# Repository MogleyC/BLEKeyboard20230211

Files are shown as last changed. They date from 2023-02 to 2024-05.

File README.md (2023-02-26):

# BLEKeyboard20230211

해당 제작물의 모든 소유권(소스,정보,파일,개발과정, 결과물 등)은 Mogley가 갖는다.
Mogley가 지정한 소속 관리자 및 개별 지정 담당자 외 일체의 열람/복사/사용을 금한다.
무단 열람/복사/사용이 되는 경우 해당 개인/단체에 법적 책임을 물을 수 있다.
이 외 상세사항 및 권한변경은 Mogley가 지정한 규정에 의거한다.

BLEKeyboard20230211는 주로 BLEKeyboard를 개발/관리를 위해 제작되었다.
BLEKeyboard의 주 개발 목표는 다음과 같다.
 - nRF MCU를 통한 프로젝트 개발
 - 프로젝트 회로도 및 PCB 설계 및 제작
 - 제품의 실제 구현 및 그에 필요한 작업 일체에 대한 개발 내용 정리

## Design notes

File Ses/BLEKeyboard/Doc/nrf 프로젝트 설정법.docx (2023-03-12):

NRF 프로젝트 설정법

# I. 신규 프로젝트 생성 및 설정

## New Solution & New Project(File->New Project)

### C/C++ executable for Nordic Semiconductor nRF

### Target Processor : nRF52832_xxAA or nRF52810_xxAA

### Compiler : gcc

### Additional Output Format : hex

### Printf Integer Support : Long

### Printf Width/Precision Supported : Yes

### Scanf Integer Support : Long)

### Select files to add to project : Files 및 Import all files and package files 체크 해제. nRF5_SDK파일들을 이용한다.

## nRF5_SDK용 config setting

### 다음의 두개의 파일을 복사

#### nRF5_SDK 폴더/config/칩셋종류/config/sdk_config.h

#### nRF5_SDK 폴더/config/칩셋종류/ses/flash_placement.xml

#### 단, 참고하고자 하는 SDK 샘플이 있는 경우 해당 프로젝트에 있는 파일을 복사

### 다음의 위치에 붙여넣기

#### SRC/칩셋종류/

### sdk_config.h의 사용하는 칩셋/모듈에 따라 셋팅 값을 조정해 주어야 한다.

## 프로젝트 설정(프로젝트 우클릭->Optoin->BuildType : Common)

### Build

#### Project Directory : nRF52832 (Optional)

#### Project Macoros

nRFSdkVer=nrf52832

nRFSoftDeviceVer=s132

nRFSdkPath=../../nRF5_SDK

SrcPath=../SRC

CMSIS_CONFIG_TOOL=../../nRF5_SDK/external_tools/cmsisconfig/CMSIS_Configuration_Wizard.jar

(빌드에 따라 nRFSdkVer와 nRFSoftDeviceVer를 수정할 것)

#### Property Groups File : None

### Code Generation

#### Debugging Level : Level3 (Optional for DebugBuild)

### Library

#### Library I/O : None

### Linker

#### Linker : GNU

#### Memory Map File : None

#### Memory Segments : FLASH1 RX 0x0 0x80000;RAM1 RWX 0x20000000 0x10000 (참고하고자 하는 SDK 샘플에서 확인)

#### Section Placement File : $(SrcPath)/$(nRFSdkVer)/$(nRFSoftDeviceVer)/flash_placement.xml

#### Section Placement Macros : 참고하고자 하는 SDK 샘플에서 확인

### Preprocessor

#### Preprocessor Definitions

NRF52832_XXAA

NRF52

NRF52_PAN_74

FLOAT_ABI_HARD

CONFIG_GPIO_AS_PINRESET

INITIALIZE_USER_SECTIONS

S132

SOFTDEVICE_PRESENT

NO_VTOR_CONFIG

NRF_SD_BLE_API_VERSION=7

APP_TIMER_V2

APP_TIMER_V2_RTC1_ENABLED

(빌드에 따라 NRF528xx_XXAA와 S1xx를 수정할 것)

(참고하고자 하는 SDK 샘플에서 확인. 특히 소프트디바이스 버전 부분-S132)

#### User Incldue Directories

$(SrcPath)

$(SrcPath)/$(nRFSdkVer)/$(nRFSoftDeviceVer)

$(nRFSdkPath)/modules/nrfx/mdk

$(nRFSdkPath)/components

$(nRFSdkPath)/components/libraries/util

$(nRFSdkPath)/components/toolchain/cmsis/include

$(nRFSdkPath)/components/softdevice/common

$(nRFSdkPath)/components/softdevice/s132/headers

$(nRFSdkPath)/components/softdevice/s132/headers/nrf52

(이 외 참조할 폴더를 모두 넣기)

(절대참조가 아닌 상대참조$(nRFSdkPath)로 수정할것)

(참고하고자 하는 SDK 샘플에서 확인. 특히 소프트디바이스 버전 부분-S132)

### Printf/Scanf

#### Printf Integer Support : Long

#### Printf Width/Precision Supported : Yes

#### Scanf Integer Support : Long)

### Runtime Memory Area

#### Heap Size : 8192 (Optional) (참고하고자 하는 SDK 샘플에서 확인)

#### Main Stack Size : 8192 (Optional) (참고하고자 하는 SDK 샘플에서 확인)

#### Process Stack Size : 0 (Optional) (참고하고자 하는 SDK 샘플에서 확인)

### Debugger

#### Register Definition File : $(nRFSdkPath)/modules/nrfx/mdk/nrf52.svd

#### Starting Stack Pointer Value : none (Optional)

### Loader

#### Additional Load File[0] : $(nRFSdkPath)/components/softdevice/s132/hex/s132_nrf52_7.2.0_softdevice.hex

##### 빌드에 따라 소프트디바이스 버전을 변경할 것

### Simulator

#### Memory Simulation Parameter : RWX 00000000,00100000,FFFFFFFF;RWX 20000000,00010000,CDCDCDCD

### Target Script

### Reset Script : TargetInterface.resetAndStop()

## 프로젝트 폴더 설정 및 기본 파일 복사

### 프로젝트 우클릭 -> Open Solution in Editor에 아래 내용을 프로젝트 안쪽에 삽입

<folder Name="Application">

<folder Name="SRC" />

<file file_name="$(SrcPath)/main.c" />

</folder>

<folder Name="System Files">

<folder Name="Segger Startup Files">

<file file_name="C:/Program Files/SEGGER/SEGGER Embedded Studio for ARM 7.10/source/thumb_crt0.s" />

</folder>

<folder Name="nRF_Segger_RTT">

<file file_name="$(nRFSdkPath)/external/segger_rtt/SEGGER_RTT.c" />

<file file_name="$(nRFSdkPath)/external/segger_rtt/SEGGER_RTT_Syscalls_SES.c">

<configuration Name="Common" build_exclude_from_build="Yes" />

</file>

<file file_name="$(nRFSdkPath)/external/segger_rtt/SEGGER_RTT_printf.c" />

</folder>

<file file_name="$(nRFSdkPath)/modules/nrfx/mdk/ses_startup_nrf52.s" />

<file file_name="$(nRFSdkPath)/modules/nrfx/mdk/ses_startup_nrf_common.s" />

<file file_name="$(nRFSdkPath)/modules/nrfx/mdk/system_nrf52.c" />

</folder>

<folder Name="nRF_ SDK">

<file file_name="$(SrcPath)/$(nRFSdkVer)/$(nRFSoftDeviceVer)/sdk_config.h" />

</folder>

(이 외 참조할 폴더&파일을 모두 넣기)

(절대참조가 아닌 상대참조로 수정할것)

(참고하고자 하는 SDK 샘플에서 확인)

### 구성요소

#### Application : main.c

##### SRC : 직접 제작된 소스파일들

#### System Files : ses_startup_nrf_common.s ses_startup_nrf52.s system_nrf52.c

##### nRF_Segger_RTT : SEGGER_RTT.c SEGGER_RTT_printf.c SEGGER_RTT_Syscalls_SES.c

##### Segger Startup Files: thumb_crt0.s

#### nRF_ SDK : sdk_config.h

##### nRF SDK 폴더 & 소스파일들

## SEGGER_RTT_Syscalls_SES.c 오류 수정

### https://jeonhj.tistory.com/65 참고

### “SEGGER_RTT_Syscalls_SES.c” 우클릭 -> Exclude From Build 선택

### Flash_placement.xml에서 다음을 삭제

#### name=".text" 옆의 size="0x4"를 삭제

#### name=".rodata" 옆의 size="0x4"를 삭제

## 빌드 테스트

### Main.C

#include <stdint.h>

#include <stdio.h>

int main()

{

while (1) {}

}

### 빌드하였을 경우 성공해야 정상 설정 완료

### 이후 코드 작성 시작

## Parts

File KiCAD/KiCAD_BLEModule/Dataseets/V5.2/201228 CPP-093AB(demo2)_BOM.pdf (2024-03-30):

Description | Comment | TYPE | MAKER | Quantity | Designator
CHIP CERAMIC CAP | 101K/250V | 2012 | WALSIN, SAMSUNG | 14 | C17, C19, C24, C25, C26, C27, C28, C29, C31, C32, C36, C37, C39, C40
CHIP CERAMIC CAP | 103K/25V | 1608 | WALSIN, SAMSUNG | 0 | C11, C12
CHIP CERAMIC CAP | 103K/25V | 1608 | WALSIN, SAMSUNG | 5 | C23, C38, C45, C50, C51
CHIP CERAMIC CAP | 104Z/25V | 1608 | WALSIN, SAMSUNG | 8 | C1, C2, C3, C4, C5, C7, C13, C14
CHIP CERAMIC CAP | 105Z/6.3V | 1608 | WALSIN, SAMSUNG | 1 | C8
CHIP CERAMIC CAP | 105Z/6.3V | 1608 | WALSIN, SAMSUNG | 0 | C9, C10
CHIP CERAMIC CAP | FS43X105K251EGG | 4532 | WALSIN | 8 | C21, C22, C34, C35, C43, C44, C48, C49
CHIP CERAMIC CAP | TCC1206X7R103K251DT | 3216 | CCTC | 4 | C20, C33, C42, C47
CHIP LED RED | WR106SR-W | 1608 | BRIGHT LED | 7 | D1, D2, D3, D4, D5, D6, D7
CHIP LED RGB | BL-HBHG8JE36K-TRB-T05 | 1615 | BRIGHT LED | 5 | RGB1, RGB2, RGB3, RGB4, RGB5
CHIP RESISTOR | 0RJ | 6432 | WALSIN, SAMSUNG | 1 | R138
CHIP RESISTOR | 1KF | 1608 | WALSIN, SAMSUNG | 29 | .
CHIP RESISTOR | 1KF | 1608 | WALSIN, SAMSUNG | 0 | R23, R24
CHIP RESISTOR | 2.7KF | 1608 | WALSIN, SAMSUNG | 12 | R34, R35, R36, R37, R56, R57, R58, R62, R63, R64, R65, R68
CHIP RESISTOR | 4.7KF | 1608 | WALSIN, SAMSUNG | 2 | R26, R27
CHIP RESISTOR | 8.2KF | 1608 | WALSIN, SAMSUNG | 4 | R45, R71, R95, R125
CHIP RESISTOR | 10KJ | 1608 | WALSIN, SAMSUNG | 1 | R1
CHIP RESISTOR | 10KJ | 1608 | WALSIN, SAMSUNG | 0 | R20, R21, R22
CHIP RESISTOR | 22KJ | 1608 | WALSIN, SAMSUNG | 0 | R25
CHIP RESISTOR | 47RJ | 1608 | WALSIN, SAMSUNG | 5 | R15, R16, R17, R18, R19
CHIP RESISTOR | 100KJ | 1608 | WALSIN, SAMSUNG | 52 | R32, R33, R39, R40, R44, R46, R48, R49, R51, R54, R55, R60, R61, R70, R72, R74, R75, R77, R80, R81, R82, R83, R85, R86, R87, R88, R94, R96, R98, R99, R101, R102, R104, R105, R107, R110, R111, R112, R113, R115, R116, R117, R118, R124, R126, R128, R129, R131, R132, R134, R135, R137
CHIP RESISTOR | 100RJ | 1608 | WALSIN, SAMSUNG | 4 | R43, R69, R93, R123
CHIP RESISTOR | 120RJ | 3216 | WALSIN, SAMSUNG | 4 | R31, R53, R79, R109
CHIP RESISTOR | 150KF | 2012 | WALSIN, SAMSUNG | 8 | R30, R38, R52, R59, R78, R84, R108, R114
CHIP RESISTOR | 270RF | 1608 | WALSIN, SAMSUNG | 1 | R28
CHIP RESISTOR | 390RJ | 1608 | WALSIN, SAMSUNG | 6 | R2, R3, R4, R5, R6, R7
CHIP RESISTOR | 510RF | 1608 | WALSIN, SAMSUNG | 1 | R29
CHIP TRANSISTOR | 2N5401S | SOT-23 | FIRST SILICON | 12 | Q7, Q8, Q13, Q14, Q19, Q20, Q21, Q22, Q31, Q32, Q33, Q34
CHIP TRANSISTOR | 2N5551S | SOT-23 | FIRST SILICON | 24 | Q9, Q10, Q11, Q12, Q15, Q16, Q17, Q18, Q23, Q24, Q25, Q26, Q27, Q28, Q29, Q30, Q35, Q36, Q37, Q38, Q39, Q40, Q41, Q42
CHIP TRANSISTOR | 2SA1981SY | SOT-23 | AUK | 6 | Q1, Q2, Q3, Q4, Q5, Q6
PIN HEADER | SMW2.5MM-7P | DIP-8 | YEONHO ELECTRONICS | 0 | CN1
SMD AMPLIFIER 1W | AP4890 | SOP8 | APLUS | 0 | U4
SMD BUFFER | ULN2003D1013TR | SOP-16 | STMicroelectronics | 1 | U5
SMD DIODE SCHOTTKY | MBRAF3200T3G | SMA | MDD, ON SEMICONDUCTOR | 4 | D8, D9, D10, D11
SMD DIODE TVS | SMBJ15A | SMB | SAMYANG ELECTRONICS | 1 | TVS1
SMD ELECT CAPACITOR | 220uF/6.3V | SC 6.3X5.8 | SAMYOUNG | 7 | C6, C15, C16, C18, C30, C41, C46
SMD INDUCTOR | SC7850D-221K | 7850 | SUHKWANG | 4 | L1, L2, L3, L4
SMD JACK USB C TYPE | USB-TYPE-C-31-M-17 | SMD-6 | Korean-Hroparts-Elec | 1 | CN4
SMD MCU | STM32G070RBT6 | LQFP64 | STMicroelectronics | 1 | U1
SMD MOSFET N-CHANNEL | FDT86246L | SOT223 | FAIRCHILD | 4 | FET1, FET2, FET3, FET4
SMD REGULATOR | LMT117-ADJ | SOT-223 | TGS | 1 | U6
SMD SERIAL FLASH | W25Q32JVSSIQ | SOIC-8(208mil) | WINBOND | 0 | U2
SMD VOICE | VLN1MM04S8X | SOP-8 | SYNOOS | 1 | U3
SMD WAFER | 12505WR-02 | SMD-2 | YEONHO ELECTRONICS | 1 | CN2
SMD WAFER | 12505WR-02 | SMD-2 | YEONHO ELECTRONICS | 0 | CN3
SMD WAFER | 12505WS-08(STRAIGHT) | SMD-8 | YEONHO ELECTRONICS | 1 | CN6
SMD WAFER | 12505WS-09(STRAIGHT) | SMD-9 | YEONHO ELECTRONICS | 1 | CN5
SPEAKER | TDM15A-8-L055C0.5S-0.3D | ASS'Y | NCEI | 1 | SPK1

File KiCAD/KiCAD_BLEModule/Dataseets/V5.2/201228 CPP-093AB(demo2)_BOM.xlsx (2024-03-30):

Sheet: Bill of Materials-CPP-093AB_2
Description | Comment | TYPE | MAKER | Quantity | Designator | Quantity검토수식
CHIP CERAMIC CAP | 101K/250V | 2012 | WALSIN, SAMSUNG | 14 | C17, C19, C24, C25, C26, C27, C28, C29, C31, C32, C36, C37, C39, C40 | 14 | OK
CHIP CERAMIC CAP | 103K/25V | 1608 | WALSIN, SAMSUNG | 0 | C11, C12 | 2 | Zero
CHIP CERAMIC CAP | 103K/25V | 1608 | WALSIN, SAMSUNG | 5 | C23, C38, C45, C50, C51 | 5 | OK
CHIP CERAMIC CAP | 104Z/25V | 1608 | WALSIN, SAMSUNG | 8 | C1, C2, C3, C4, C5, C7, C13, C14 | 8 | OK
CHIP CERAMIC CAP | 105Z/6.3V | 1608 | WALSIN, SAMSUNG | 1 | C8 | 1 | OK
CHIP CERAMIC CAP | 105Z/6.3V | 1608 | WALSIN, SAMSUNG | 0 | C9, C10 | 2 | Zero
CHIP CERAMIC CAP | FS43X105K251EGG | 4532 | WALSIN | 8 | C21, C22, C34, C35, C43, C44, C48, C49 | 8 | OK
CHIP CERAMIC CAP | TCC1206X7R103K251DT | 3216 | CCTC | 4 | C20, C33, C42, C47 | 4 | OK
CHIP LED RED | WR106SR-W | 1608 | BRIGHT LED | 7 | D1, D2, D3, D4, D5, D6, D7 | 7 | OK
CHIP LED RGB | BL-HBHG8JE36K-TRB-T05 | 1615 | BRIGHT LED | 5 | RGB1, RGB2, RGB3, RGB4, RGB5 | 5 | OK
CHIP RESISTOR | 0RJ | 6432 | WALSIN, SAMSUNG | 1 | R138 | 1 | OK
CHIP RESISTOR | 1KF | 1608 | WALSIN, SAMSUNG | 29 | R11, R12, R13, R14, R41, R42, R47, R50, R66, R67, R73, R76, R89, R90, R91, R92, R97, R100, R103, R106, R119, R120, R121, R122, R127, R130, R133, R136, R139 | 29 | OK
CHIP RESISTOR | 1KF | 1608 | WALSIN, SAMSUNG | 0 | R23, R24 | 2 | Zero
CHIP RESISTOR | 2.7KF | 1608 | WALSIN, SAMSUNG | 12 | R34, R35, R36, R37, R56, R57, R58, R62, R63, R64, R65, R68 | 12 | OK
CHIP RESISTOR | 4.7KF | 1608 | WALSIN, SAMSUNG | 2 | R26, R27 | 2 | OK
CHIP RESISTOR | 8.2KF | 1608 | WALSIN, SAMSUNG | 4 | R45, R71, R95, R125 | 4 | OK
CHIP RESISTOR | 10KJ | 1608 | WALSIN, SAMSUNG | 1 | R1 | 1 | OK
CHIP RESISTOR | 10KJ | 1608 | WALSIN, SAMSUNG | 0 | R20, R21, R22 | 3 | Zero
CHIP RESISTOR | 22KJ | 1608 | WALSIN, SAMSUNG | 0 | R25 | 1 | Zero
CHIP RESISTOR | 47RJ | 1608 | WALSIN, SAMSUNG | 5 | R15, R16, R17, R18, R19 | 5 | OK
CHIP RESISTOR | 100KJ | 1608 | WALSIN, SAMSUNG | 52 | R32, R33, R39, R40, R44, R46, R48, R49, R51, R54, R55, R60, R61, R70, R72, R74, R75, R77, R80, R81, R82, R83, R85, R86, R87, R88, R94, R96, R98, R99, R101, R102, R104, R105, R107, R110, R111, R112, R113, R115, R116, R117, R118, R124, R126, R128, R129, R131, R132, R134, R135, R137 | 52 | OK
CHIP RESISTOR | 100RJ | 1608 | WALSIN, SAMSUNG | 4 | R43, R69, R93, R123 | 4 | OK
CHIP RESISTOR | 120RJ | 3216 | WALSIN, SAMSUNG | 4 | R31, R53, R79, R109 | 4 | OK
CHIP RESISTOR | 150KF | 2012 | WALSIN, SAMSUNG | 8 | R30, R38, R52, R59, R78, R84, R108, R114 | 8 | OK
CHIP RESISTOR | 270RF | 1608 | WALSIN, SAMSUNG | 1 | R28 | 1 | OK
CHIP RESISTOR | 390RJ | 1608 | WALSIN, SAMSUNG | 6 | R2, R3, R4, R5, R6, R7 | 6 | OK
CHIP RESISTOR | 510RF | 1608 | WALSIN, SAMSUNG | 1 | R29 | 1 | OK
CHIP TRANSISTOR | 2N5401S | SOT-23 | FIRST SILICON | 12 | Q7, Q8, Q13, Q14, Q19, Q20, Q21, Q22, Q31, Q32, Q33, Q34 | 12 | OK
CHIP TRANSISTOR | 2N5551S | SOT-23 | FIRST SILICON | 24 | Q9, Q10, Q11, Q12, Q15, Q16, Q17, Q18, Q23, Q24, Q25, Q26, Q27, Q28, Q29, Q30, Q35, Q36, Q37, Q38, Q39, Q40, Q41, Q42 | 24 | OK
CHIP TRANSISTOR | 2SA1981SY | SOT-23 | AUK | 6 | Q1, Q2, Q3, Q4, Q5, Q6 | 6 | OK
PIN HEADER | SMW2.5MM-7P | DIP-8 | YEONHO ELECTRONICS | 0 | CN1 | 1 | Zero
SMD AMPLIFIER 1W | AP4890 | SOP8 | APLUS | 0 | U4 | 1 | Zero
SMD BUFFER | ULN2003D1013TR | SOP-16 | STMicroelectronics | 1 | U5 | 1 | OK
SMD DIODE SCHOTTKY | MBRAF3200T3G | SMA | MDD, ON SEMICONDUCTOR | 4 | D8, D9, D10, D11 | 4 | OK
SMD DIODE TVS | SMBJ15A | SMB | SAMYANG ELECTRONICS | 1 | TVS1 | 1 | OK
SMD ELECT CAPACITOR | 220uF/6.3V | SC 6.3X5.8 | SAMYOUNG | 7 | C6, C15, C16, C18, C30, C41, C46 | 7 | OK
SMD INDUCTOR | SC7850D-221K | 7850 | SUHKWANG | 4 | L1, L2, L3, L4 | 4 | OK
SMD JACK USB C TYPE | USB-TYPE-C-31-M-17 | SMD-6 | Korean-Hroparts-Elec | 1 | CN4 | 1 | OK
SMD MCU | STM32G070RBT6 | LQFP64 | STMicroelectronics | 1 | U1 | 1 | OK
SMD MOSFET N-CHANNEL | FDT86246L | SOT223 | FAIRCHILD | 4 | FET1, FET2, FET3, FET4 | 4 | OK
SMD REGULATOR | LMT117-ADJ | SOT-223 | TGS | 1 | U6 | 1 | OK
SMD SERIAL FLASH | W25Q32JVSSIQ | SOIC-8(208mil) | WINBOND | 0 | U2 | 1 | Zero
SMD VOICE | VLN1MM04S8X | SOP-8 | SYNOOS | 1 | U3 | 1 | OK
SMD WAFER | 12505WR-02 | SMD-2 | YEONHO ELECTRONICS | 1 | CN2 | 1 | OK
SMD WAFER | 12505WR-02 | SMD-2 | YEONHO ELECTRONICS | 0 | CN3 | 1 | Zero
SMD WAFER | 12505WS-08(STRAIGHT) | SMD-8 | YEONHO ELECTRONICS | 1 | CN6 | 1 | OK
SMD WAFER | 12505WS-09(STRAIGHT) | SMD-9 | YEONHO ELECTRONICS | 1 | CN5 | 1 | OK
SPEAKER | TDM15A-8-L055C0.5S-0.3D | ASS'Y | NCEI | 1 | SPK1 | 1 | OK
 |  |  |  |  |  | 14 | ZeroSum

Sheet: Bill of Materials-CPP-093AB
Description | Comment | TYPE | MAKER | Quantity | Designator
CHIP CERAMIC CAP | 101K/250V | 2012 | WALSIN, SAMSUNG | 14 | C17, C19, C24, C25, C26, C27, C28, C29, C31, C32, C36, C37, C39, C40
CHIP CERAMIC CAP | 103K/25V | 1608 | WALSIN, SAMSUNG | 7 | C11, C12, C23, C38, C45, C50, C51
CHIP CERAMIC CAP | 104Z/25V | 1608 | WALSIN, SAMSUNG | 8 | C1, C2, C3, C4, C5, C7, C13, C14
CHIP CERAMIC CAP | 105Z/6.3V | 1608 | WALSIN, SAMSUNG | 3 | C8, C9, C10
CHIP CERAMIC CAP | FS43X105K251EGG | 4532 | WALSIN | 8 | C21, C22, C34, C35, C43, C44, C48, C49
CHIP CERAMIC CAP | TCC1206X7R103K251DT | 3216 | CCTC | 4 | C20, C33, C42, C47
CHIP LED RED | WR106SR-W | 1608 | BRIGHT LED | 7 | D1, D2, D3, D4, D5, D6, D7
CHIP LED RGB | BL-HBHG8JE36K-TRB-T05 | 1615 | BRIGHT LED | 5 | RGB1, RGB2, RGB3, RGB4, RGB5
CHIP RESISTOR | 0RJ | 6432 | WALSIN, SAMSUNG | 1 | R138
CHIP RESISTOR | 1KF | 1608 | WALSIN, SAMSUNG | 31 | R11, R12, R13, R14, R23, R24, R41, R42, R47, R50, R66, R67, R73, R76, R89, R90, R91, R92, R97, R100, R103, R106, R119, R120, R121, R122, R127, R130, R133, R136, R139
CHIP RESISTOR | 2.7KF | 1608 | WALSIN, SAMSUNG | 12 | R34, R35, R36, R37, R56, R57, R58, R62, R63, R64, R65, R68
CHIP RESISTOR | 4.7KF | 1608 | WALSIN, SAMSUNG | 2 | R26, R27
CHIP RESISTOR | 8.2KF | 1608 | WALSIN, SAMSUNG | 4 | R45, R71, R95, R125
CHIP RESISTOR | 10KJ | 1608 | WALSIN, SAMSUNG | 4 | R1, R20, R21, R22
CHIP RESISTOR | 22KJ | 1608 | WALSIN, SAMSUNG | 1 | R25
CHIP RESISTOR | 47RJ | 1608 | WALSIN, SAMSUNG | 5 | R15, R16, R17, R18, R19
CHIP RESISTOR | 100KJ | 1608 | WALSIN, SAMSUNG | 52 | R32, R33, R39, R40, R44, R46, R48, R49, R51, R54, R55, R60, R61, R70, R72, R74, R75, R77, R80, R81, R82, R83, R85, R86, R87, R88, R94, R96, R98, R99, R101, R102, R104, R105, R107, R110, R111, R112, R113, R115, R116, R117, R118, R124, R126, R128, R129, R131, R132, R134, R135, R137
CHIP RESISTOR | 100RJ | 1608 | WALSIN, SAMSUNG | 4 | R43, R69, R93, R123
CHIP RESISTOR | 120RJ | 3216 | WALSIN, SAMSUNG | 4 | R31, R53, R79, R109
CHIP RESISTOR | 150KF | 2012 | WALSIN, SAMSUNG | 8 | R30, R38, R52, R59, R78, R84, R108, R114
CHIP RESISTOR | 270RF | 1608 | WALSIN, SAMSUNG | 1 | R28
CHIP RESISTOR | 390RJ | 1608 | WALSIN, SAMSUNG | 6 | R2, R3, R4, R5, R6, R7
CHIP RESISTOR | 510RF | 1608 | WALSIN, SAMSUNG | 1 | R29
CHIP TRANSISTOR | 2N5401S | SOT-23 | FIRST SILICON | 12 | Q7, Q8, Q13, Q14, Q19, Q20, Q21, Q22, Q31, Q32, Q33, Q34
CHIP TRANSISTOR | 2N5551S | SOT-23 | FIRST SILICON | 24 | Q9, Q10, Q11, Q12, Q15, Q16, Q17, Q18, Q23, Q24, Q25, Q26, Q27, Q28, Q29, Q30, Q35, Q36, Q37, Q38, Q39, Q40, Q41, Q42
CHIP TRANSISTOR | 2SA1981SY | SOT-23 | AUK | 6 | Q1, Q2, Q3, Q4, Q5, Q6
PIN HEADER | SMW2.5MM-7P | DIP-8 | YEONHO ELECTRONICS | 0 | CN1
SMD AMPLIFIER 1W | AP4890 | SOP8 | APLUS | 0 | U4
SMD BUFFER | ULN2003D1013TR | SOP-16 | STMicroelectronics | 1 | U5
SMD DIODE SCHOTTKY | MBRAF3200T3G | SMA | MDD, ON SEMICONDUCTOR | 4 | D8, D9, D10, D11
SMD DIODE TVS | SMBJ15A | SMB | SAMYANG ELECTRONICS | 1 | TVS1
SMD ELECT CAPACITOR | 220uF/6.3V | SC 6.3X5.8 | SAMYOUNG | 7 | C6, C15, C16, C18, C30, C41, C46
SMD INDUCTOR | SC7850D-221K | 7850 | SUHKWANG | 4 | L1, L2, L3, L4
SMD JACK USB C TYPE | USB-TYPE-C-31-M-17 | SMD-6 | Korean-Hroparts-Elec | 1 | CN4
SMD MCU | STM32G070RBT6 | LQFP64 | STMicroelectronics | 1 | U1
SMD MOSFET N-CHANNEL | FDT86246L | SOT223 | FAIRCHILD | 4 | FET1, FET2, FET3, FET4
SMD REGULATOR | LMT117-ADJ | SOT-223 | TGS | 1 | U6
SMD SERIAL FLASH | W25Q32JVSSIQ | SOIC-8(208mil) | WINBOND | 0 | U2
SMD VOICE | VLN1MM04S8X | SOP-8 | SYNOOS | 1 | U3
SMD WAFER | 12505WR-02 | SMD-2 | YEONHO ELECTRONICS | 2 | CN2, CN3
SMD WAFER | 12505WS-08(STRAIGHT) | SMD-8 | YEONHO ELECTRONICS | 1 | CN6
SMD WAFER | 12505WS-09(STRAIGHT) | SMD-9 | YEONHO ELECTRONICS | 1 | CN5
SPEAKER | TDM15A-8-L055C0.5S-0.3D | ASS'Y | NCEI | 1 | SPK1

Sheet: bom
Description | Comment | TYPE | MAKER | Quantity | Designator
CHIP CERAMIC CAP | 101K/250V | 2012 | WALSIN, SAMSUNG | 14 | C17 C19 C24 C25 C26 C27 C28 C29 C31 C32 C36 C37 C39 C40 | CHIP CERAMIC CAP101K/250V2012WALSIN, SAMSUNG | 3 | TRUE | TRUE
CHIP CERAMIC CAP | 103K/25V | 1608 | WALSIN, SAMSUNG | 7 | C11 C12 C23 C38 C45 C50 C51 | CHIP CERAMIC CAP103K/25V1608WALSIN, SAMSUNG | 2 | TRUE | TRUE
CHIP CERAMIC CAP | 104Z/25V | 1608 | WALSIN, SAMSUNG | 8 | C1 C2 C3 C4 C5 C7 C13 C14 | CHIP CERAMIC CAP104Z/25V1608WALSIN, SAMSUNG | 6 | TRUE | TRUE
CHIP CERAMIC CAP | 105Z/6.3V | 1608 | WALSIN, SAMSUNG | 3 | C8 C9 C10 | CHIP CERAMIC CAP105Z/6.3V1608WALSIN, SAMSUNG | 8 | TRUE | TRUE
CHIP CERAMIC CAP | FS43X105K251EGG | 4532 | WALSIN | 8 | C21 C22 C34 C35 C43 C44 C48 C49 | CHIP CERAMIC CAPFS43X105K251EGG4532WALSIN | 5 | TRUE | TRUE
CHIP CERAMIC CAP | TCC1206X7R103K251DT | 3216 | CCTC | 4 | C20 C33 C42 C47 | CHIP CERAMIC CAPTCC1206X7R103K251DT3216CCTC | 4 | TRUE | TRUE
CHIP LED RED | WR106SR-W | 1608 | BRIGHT LED | 7 | D1 D2 D3 D4 D5 D6 D7 | CHIP LED REDWR106SR-W1608BRIGHT LED | 14 | TRUE | TRUE
CHIP LED RGB | BL-HBHG8JE36K-TRB-T05 | 1615 | BRIGHT LED | 5 | RGB1 RGB2 RGB3 RGB4 RGB5 | CHIP LED RGBBL-HBHG8JE36K-TRB-T051615BRIGHT LED | 38 | TRUE | TRUE
CHIP RESISTOR | 0RJ | 6432 | WALSIN, SAMSUNG | 1 | R138 | CHIP RESISTOR0RJ6432WALSIN, SAMSUNG | 24 | TRUE | TRUE
CHIP RESISTOR | 1KF | 1608 | WALSIN, SAMSUNG | 31 | R11 R12 R13 R14 R23 R24 R41 R42 R47 R50 R66 R67 R73 R76 R89 R90 R91 R92 R97 R100 R103 R106 R119 R120 R121 R122 R127 R130 R133 R136 R139 | CHIP RESISTOR1KF1608WALSIN, SAMSUNG | 23 | TRUE | TRUE
CHIP RESISTOR | 2.7KF | 1608 | WALSIN, SAMSUNG | 12 | R34 R35 R36 R37 R56 R57 R58 R62 R63 R64 R65 R68 | CHIP RESISTOR2.7KF1608WALSIN, SAMSUNG | 33 | TRUE | TRUE
CHIP RESISTOR | 4.7KF | 1608 | WALSIN, SAMSUNG | 2 | R26 R27 | CHIP RESISTOR4.7KF1608WALSIN, SAMSUNG | 28 | TRUE | TRUE
CHIP RESISTOR | 8.2KF | 1608 | WALSIN, SAMSUNG | 4 | R45 R71 R95 R125 | CHIP RESISTOR8.2KF1608WALSIN, SAMSUNG | 36 | TRUE | TRUE
CHIP RESISTOR | 10KJ | 1608 | WALSIN, SAMSUNG | 4 | R1 R20 R21 R22 | CHIP RESISTOR10KJ1608WALSIN, SAMSUNG | 22 | TRUE | TRUE
CHIP RESISTOR | 22KJ | 1608 | WALSIN, SAMSUNG | 1 | R25 | CHIP RESISTOR22KJ1608WALSIN, SAMSUNG | 27 | TRUE | TRUE
CHIP RESISTOR | 47RJ | 1608 | WALSIN, SAMSUNG | 5 | R15 R16 R17 R18 R19 | CHIP RESISTOR47RJ1608WALSIN, SAMSUNG | 25 | TRUE | TRUE
CHIP RESISTOR | 100KJ | 1608 | WALSIN, SAMSUNG | 52 | R32 R33 R39 R40 R44 R46 R48 R49 R51 R54 R55 R60 R61 R70 R72 R74 R75 R77 R80 R81 R82 R83 R85 R86 R87 R88 R94 R96 R98 R99 R101 R102 R104 R105 R107 R110 R111 R112 R113 R115 R116 R117 R118 R124 R126 R128 R129 R131 R132 R134 R135 R137 | CHIP RESISTOR100KJ1608WALSIN, SAMSUNG | 35 | TRUE | TRUE
CHIP RESISTOR | 100RJ | 1608 | WALSIN, SAMSUNG | 4 | R43 R69 R93 R123 | CHIP RESISTOR100RJ1608WALSIN, SAMSUNG | 34 | TRUE | TRUE
CHIP RESISTOR | 120RJ | 3216 | WALSIN, SAMSUNG | 4 | R31 R53 R79 R109 | CHIP RESISTOR120RJ3216WALSIN, SAMSUNG | 32 | TRUE | TRUE
CHIP RESISTOR | 150KF | 2012 | WALSIN, SAMSUNG | 8 | R30 R38 R52 R59 R78 R84 R108 R114 | CHIP RESISTOR150KF2012WALSIN, SAMSUNG | 31 | TRUE | TRUE
CHIP RESISTOR | 270RF | 1608 | WALSIN, SAMSUNG | 1 | R28 | CHIP RESISTOR270RF1608WALSIN, SAMSUNG | 29 | TRUE | TRUE
CHIP RESISTOR | 390RJ | 1608 | WALSIN, SAMSUNG | 6 | R2 R3 R4 R5 R6 R7 | CHIP RESISTOR390RJ1608WALSIN, SAMSUNG | 26 | TRUE | TRUE
CHIP RESISTOR | 510RF | 1608 | WALSIN, SAMSUNG | 1 | R29 | CHIP RESISTOR510RF1608WALSIN, SAMSUNG | 30 | TRUE | TRUE
CHIP TRANSISTOR | 2N5401S | SOT-23 | FIRST SILICON | 12 | Q7 Q8 Q13 Q14 Q19 Q20 Q21 Q22 Q31 Q32 Q33 Q34 | CHIP TRANSISTOR2N5401SSOT-23FIRST SILICON | 20 | TRUE | TRUE
CHIP TRANSISTOR | 2N5551S | SOT-23 | FIRST SILICON | 24 | Q9 Q10 Q11 Q12 Q15 Q16 Q17 Q18 Q23 Q24 Q25 Q26 Q27 Q28 Q29 Q30 Q35 Q36 Q37 Q38 Q39 Q40 Q41 Q42 | CHIP TRANSISTOR2N5551SSOT-23FIRST SILICON | 21 | TRUE | TRUE
CHIP TRANSISTOR | 2SA1981SY | SOT-23 | AUK | 6 | Q1 Q2 Q3 Q4 Q5 Q6 | CHIP TRANSISTOR2SA1981SYSOT-23AUK | 19 | TRUE | TRUE
PIN HEADER | SMW2.5MM-7P | DIP-8 | YEONHO ELECTRONICS | 1 | CN1 | PIN HEADERSMW2.5MM-7PDIP-8YEONHO ELECTRONICS | 9 | TRUE | TRUE
SMD AMPLIFIER 1W | AP4890 | SOP8 | APLUS | 1 | U4 | SMD AMPLIFIER 1WAP4890SOP8APLUS | 43 | TRUE | TRUE
SMD BUFFER | ULN2003D1013TR | SOP-16 | STMicroelectronics | 1 | U5 | SMD BUFFERULN2003D1013TRSOP-16STMicroelectronics | 44 | TRUE | TRUE
SMD DIODE SCHOTTKY | MBRAF3200T3G | SMA | MDD, ON SEMICONDUCTOR | 4 | D8 D9 D10 D11 | SMD DIODE SCHOTTKYMBRAF3200T3GSMAMDD, ON SEMICONDUCTOR | 15 | TRUE | TRUE
SMD DIODE TVS | SMBJ15A | SMB | SAMYANG ELECTRONICS | 1 | TVS1 | SMD DIODE TVSSMBJ15ASMBSAMYANG ELECTRONICS | 39 | TRUE | TRUE
SMD ELECT CAPACITOR | 220uF/6.3V | SC 6.3X5.8 | SAMYOUNG | 7 | C6 C15 C16 C18 C30 C41 C46 | SMD ELECT CAPACITOR220uF/6.3VSC 6.3X5.8SAMYOUNG | 7 | TRUE | TRUE
SMD INDUCTOR | SC7850D-221K | 7850 | SUHKWANG | 4 | L1 L2 L3 L4 | SMD INDUCTORSC7850D-221K7850SUHKWANG | 18 | TRUE | TRUE
SMD JACK USB C TYPE | USB-TYPE-C-31-M-17 | SMD-6 | Korean-Hroparts-Elec | 1 | CN4 | SMD JACK USB C TYPEUSB-TYPE-C-31-M-17SMD-6Korean-Hroparts-Elec | 11 | TRUE | TRUE
SMD MCU | STM32G070RBT6 | LQFP64 | STMicroelectronics | 1 | U1 | SMD MCUSTM32G070RBT6LQFP64STMicroelectronics | 40 | TRUE | TRUE
SMD MOSFET N-CHANNEL | FDT86246L | SOT-223 | FAIRCHILD | 4 | FET1 FET2 FET3 FET4 | SMD MOSFET N-CHANNELFDT86246LSOT-223FAIRCHILD | 16 | TRUE | TRUE
SMD REGULATOR | LMT117-ADJ | SOT-223 | TGS | 1 | U6 | SMD REGULATORLMT117-ADJSOT-223TGS | 45 | TRUE | TRUE
SMD SERIAL FLASH | W25Q32JVSSIQ | SOIC-8(208mil) | WINBOND | 1 | U2 | SMD SERIAL FLASHW25Q32JVSSIQSOIC-8(208mil)WINBOND | 41 | TRUE | TRUE
SMD VOICE | VLN1MM04S8X | SOP-8 | SYNOOS | 1 | U3 | SMD VOICEVLN1MM04S8XSOP-8SYNOOS | 42 | TRUE | TRUE
SMD WAFER | 12505WR-02 | SMD-2 | YEONHO ELECTRONICS | 2 | CN2 CN3 | SMD WAFER12505WR-02SMD-2YEONHO ELECTRONICS | 10 | TRUE | TRUE
SMD WAFER | 12505WS-08 | SMD-8 | YEONHO ELECTRONICS | 1 | CN6 | SMD WAFER12505WS-08SMD-8YEONHO ELECTRONICS | 13 | TRUE | TRUE
SMD WAFER | 12505WS-09 | SMD-9 | YEONHO ELECTRONICS | 1 | CN5 | SMD WAFER12505WS-09SMD-9YEONHO ELECTRONICS | 12 | TRUE | TRUE
SPEAKER | TDM15A-8-L055C0.5S-0.3D | ASS'Y | NCEI | 1 | SPK1 | SPEAKERTDM15A-8-L055C0.5S-0.3DASS'YNCEI | #N/A | #N/A | #N/A

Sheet: Lib
 |  |  |  | 0 0 50 H I C CNN
1 | CHIP CERAMIC CAP | 4 | Description | F4 "CHIP CERAMIC CAP" 0 0 50 H I C CNN "Description"
1 | 101K/250V | 5 | Comment | F5 "101K/250V" 0 0 50 H I C CNN "Comment"
1 | 2012 | 6 | TYPE | F6 "2012" 0 0 50 H I C CNN "TYPE"
1 | WALSIN, SAMSUNG | 7 | MAKER | F7 "WALSIN, SAMSUNG" 0 0 50 H I C CNN "MAKER"
2 | CHIP CERAMIC CAP | 4 | Description | F4 "CHIP CERAMIC CAP" 0 0 50 H I C CNN "Description"
2 | 103K/25V | 5 | Comment | F5 "103K/25V" 0 0 50 H I C CNN "Comment"
2 | 1608 | 6 | TYPE | F6 "1608" 0 0 50 H I C CNN "TYPE"
2 | WALSIN, SAMSUNG | 7 | MAKER | F7 "WALSIN, SAMSUNG" 0 0 50 H I C CNN "MAKER"
3 | CHIP CERAMIC CAP | 4 | Description | F4 "CHIP CERAMIC CAP" 0 0 50 H I C CNN "Description"
3 | 104Z/25V | 5 | Comment | F5 "104Z/25V" 0 0 50 H I C CNN "Comment"
3 | 1608 | 6 | TYPE | F6 "1608" 0 0 50 H I C CNN "TYPE"
3 | WALSIN, SAMSUNG | 7 | MAKER | F7 "WALSIN, SAMSUNG" 0 0 50 H I C CNN "MAKER"
4 | CHIP CERAMIC CAP | 4 | Description | F4 "CHIP CERAMIC CAP" 0 0 50 H I C CNN "Description"
4 | 105Z/6.3V | 5 | Comment | F5 "105Z/6.3V" 0 0 50 H I C CNN "Comment"
4 | 1608 | 6 | TYPE | F6 "1608" 0 0 50 H I C CNN "TYPE"
4 | WALSIN, SAMSUNG | 7 | MAKER | F7 "WALSIN, SAMSUNG" 0 0 50 H I C CNN "MAKER"
5 | CHIP CERAMIC CAP | 4 | Description | F4 "CHIP CERAMIC CAP" 0 0 50 H I C CNN "Description"
5 | FS43X105K251EGG | 5 | Comment | F5 "FS43X105K251EGG" 0 0 50 H I C CNN "Comment"
5 | 4532 | 6 | TYPE | F6 "4532" 0 0 50 H I C CNN "TYPE"
5 | WALSIN | 7 | MAKER | F7 "WALSIN" 0 0 50 H I C CNN "MAKER"
6 | CHIP CERAMIC CAP | 4 | Description | F4 "CHIP CERAMIC CAP" 0 0 50 H I C CNN "Description"
6 | TCC1206X7R103K251DT | 5 | Comment | F5 "TCC1206X7R103K251DT" 0 0 50 H I C CNN "Comment"
6 | 3216 | 6 | TYPE | F6 "3216" 0 0 50 H I C CNN "TYPE"
6 | CCTC | 7 | MAKER | F7 "CCTC" 0 0 50 H I C CNN "MAKER"
7 | CHIP LED RED | 4 | Description | F4 "CHIP LED RED" 0 0 50 H I C CNN "Description"
7 | WR106SR-W | 5 | Comment | F5 "WR106SR-W" 0 0 50 H I C CNN "Comment"
7 | 1608 | 6 | TYPE | F6 "1608" 0 0 50 H I C CNN "TYPE"
7 | BRIGHT LED | 7 | MAKER | F7 "BRIGHT LED" 0 0 50 H I C CNN "MAKER"
8 | CHIP LED RGB | 4 | Description | F4 "CHIP LED RGB" 0 0 50 H I C CNN "Description"
8 | BL-HBHG8JE36K-TRB-T05 | 5 | Comment | F5 "BL-HBHG8JE36K-TRB-T05" 0 0 50 H I C CNN "Comment"
8 | 1615 | 6 | TYPE | F6 "1615" 0 0 50 H I C CNN "TYPE"
8 | BRIGHT LED | 7 | MAKER | F7 "BRIGHT LED" 0 0 50 H I C CNN "MAKER"
9 | CHIP RESISTOR | 5 | Description | F5 "CHIP RESISTOR" 0 0 50 H I C CNN "Description"
9 | 0RJ | 6 | Comment | F6 "0RJ" 0 0 50 H I C CNN "Comment"
9 | 6432 | 7 | TYPE | F7 "6432" 0 0 50 H I C CNN "TYPE"
9 | WALSIN, SAMSUNG | 8 | MAKER | F8 "WALSIN, SAMSUNG" 0 0 50 H I C CNN "MAKER"
10 | CHIP RESISTOR | 5 | Description | F5 "CHIP RESISTOR" 0 0 50 H I C CNN "Description"
10 | 1KF | 6 | Comment | F6 "1KF" 0 0 50 H I C CNN "Comment"
10 | 1608 | 7 | TYPE | F7 "1608" 0 0 50 H I C CNN "TYPE"
10 | WALSIN, SAMSUNG | 8 | MAKER | F8 "WALSIN, SAMSUNG" 0 0 50 H I C CNN "MAKER"
11 | CHIP RESISTOR | 5 | Description | F5 "CHIP RESISTOR" 0 0 50 H I C CNN "Description"
11 | 2.7KF | 6 | Comment | F6 "2.7KF" 0 0 50 H I C CNN "Comment"
11 | 1608 | 7 | TYPE | F7 "1608" 0 0 50 H I C CNN "TYPE"
11 | WALSIN, SAMSUNG | 8 | MAKER | F8 "WALSIN, SAMSUNG" 0 0 50 H I C CNN "MAKER"
12 | CHIP RESISTOR | 5 | Description | F5 "CHIP RESISTOR" 0 0 50 H I C CNN "Description"
12 | 4.7KF | 6 | Comment | F6 "4.7KF" 0 0 50 H I C CNN "Comment"
12 | 1608 | 7 | TYPE | F7 "1608" 0 0 50 H I C CNN "TYPE"
12 | WALSIN, SAMSUNG | 8 | MAKER | F8 "WALSIN, SAMSUNG" 0 0 50 H I C CNN "MAKER"
13 | CHIP RESISTOR | 5 | Description | F5 "CHIP RESISTOR" 0 0 50 H I C CNN "Description"
13 | 8.2KF | 6 | Comment | F6 "8.2KF" 0 0 50 H I C CNN "Comment"
13 | 1608 | 7 | TYPE | F7 "1608" 0 0 50 H I C CNN "TYPE"
13 | WALSIN, SAMSUNG | 8 | MAKER | F8 "WALSIN, SAMSUNG" 0 0 50 H I C CNN "MAKER"
14 | CHIP RESISTOR | 5 | Description | F5 "CHIP RESISTOR" 0 0 50 H I C CNN "Description"
14 | 10KJ | 6 | Comment | F6 "10KJ" 0 0 50 H I C CNN "Comment"
14 | 1608 | 7 | TYPE | F7 "1608" 0 0 50 H I C CNN "TYPE"
14 | WALSIN, SAMSUNG | 8 | MAKER | F8 "WALSIN, SAMSUNG" 0 0 50 H I C CNN "MAKER"
15 | CHIP RESISTOR | 5 | Description | F5 "CHIP RESISTOR" 0 0 50 H I C CNN "Description"
15 | 22KJ | 6 | Comment | F6 "22KJ" 0 0 50 H I C CNN "Comment"
15 | 1608 | 7 | TYPE | F7 "1608" 0 0 50 H I C CNN "TYPE"
15 | WALSIN, SAMSUNG | 8 | MAKER | F8 "WALSIN, SAMSUNG" 0 0 50 H I C CNN "MAKER"
16 | CHIP RESISTOR | 5 | Description | F5 "CHIP RESISTOR" 0 0 50 H I C CNN "Description"
16 | 47RJ | 6 | Comment | F6 "47RJ" 0 0 50 H I C CNN "Comment"
16 | 1608 | 7 | TYPE | F7 "1608" 0 0 50 H I C CNN "TYPE"
16 | WALSIN, SAMSUNG | 8 | MAKER | F8 "WALSIN, SAMSUNG" 0 0 50 H I C CNN "MAKER"
17 | CHIP RESISTOR | 5 | Description | F5 "CHIP RESISTOR" 0 0 50 H I C CNN "Description"
17 | 100KJ | 6 | Comment | F6 "100KJ" 0 0 50 H I C CNN "Comment"
17 | 1608 | 7 | TYPE | F7 "1608" 0 0 50 H I C CNN "TYPE"
17 | WALSIN, SAMSUNG | 8 | MAKER | F8 "WALSIN, SAMSUNG" 0 0 50 H I C CNN "MAKER"
18 | CHIP RESISTOR | 5 | Description | F5 "CHIP RESISTOR" 0 0 50 H I C CNN "Description"
18 | 100RJ | 6 | Comment | F6 "100RJ" 0 0 50 H I C CNN "Comment"
18 | 1608 | 7 | TYPE | F7 "1608" 0 0 50 H I C CNN "TYPE"
18 | WALSIN, SAMSUNG | 8 | MAKER | F8 "WALSIN, SAMSUNG" 0 0 50 H I C CNN "MAKER"
19 | CHIP RESISTOR | 5 | Description | F5 "CHIP RESISTOR" 0 0 50 H I C CNN "Description"
19 | 120RJ | 6 | Comment | F6 "120RJ" 0 0 50 H I C CNN "Comment"
19 | 3216 | 7 | TYPE | F7 "3216" 0 0 50 H I C CNN "TYPE"
19 | WALSIN, SAMSUNG | 8 | MAKER | F8 "WALSIN, SAMSUNG" 0 0 50 H I C CNN "MAKER"
20 | CHIP RESISTOR | 5 | Description | F5 "CHIP RESISTOR" 0 0 50 H I C CNN "Description"
20 | 150KF | 6 | Comment | F6 "150KF" 0 0 50 H I C CNN "Comment"
20 | 2012 | 7 | TYPE | F7 "2012" 0 0 50 H I C CNN "TYPE"
20 | WALSIN, SAMSUNG | 8 | MAKER | F8 "WALSIN, SAMSUNG" 0 0 50 H I C CNN "MAKER"
21 | CHIP RESISTOR | 5 | Description | F5 "CHIP RESISTOR" 0 0 50 H I C CNN "Description"
21 | 270RF | 6 | Comment | F6 "270RF" 0 0 50 H I C CNN "Comment"
21 | 1608 | 7 | TYPE | F7 "1608" 0 0 50 H I C CNN "TYPE"
21 | WALSIN, SAMSUNG | 8 | MAKER | F8 "WALSIN, SAMSUNG" 0 0 50 H I C CNN "MAKER"
22 | CHIP RESISTOR | 5 | Description | F5 "CHIP RESISTOR" 0 0 50 H I C CNN "Description"
22 | 390RJ | 6 | Comment | F6 "390RJ" 0 0 50 H I C CNN "Comment"
22 | 1608 | 7 | TYPE | F7 "1608" 0 0 50 H I C CNN "TYPE"
22 | WALSIN, SAMSUNG | 8 | MAKER | F8 "WALSIN, SAMSUNG" 0 0 50 H I C CNN "MAKER"
23 | CHIP RESISTOR | 5 | Description | F5 "CHIP RESISTOR" 0 0 50 H I C CNN "Description"
23 | 510RF | 6 | Comment | F6 "510RF" 0 0 50 H I C CNN "Comment"
23 | 1608 | 7 | TYPE | F7 "1608" 0 0 50 H I C CNN "TYPE"
23 | WALSIN, SAMSUNG | 8 | MAKER | F8 "WALSIN, SAMSUNG" 0 0 50 H I C CNN "MAKER"
24 | CHIP TRANSISTOR | 4 | Description | F4 "CHIP TRANSISTOR" 0 0 50 H I C CNN "Description"
24 | 2N5401S | 5 | Comment | F5 "2N5401S" 0 0 50 H I C CNN "Comment"
24 | SOT-23 | 6 | TYPE | F6 "SOT-23" 0 0 50 H I C CNN "TYPE"
24 | FIRST SILICON | 7 | MAKER | F7 "FIRST SILICON" 0 0 50 H I C CNN "MAKER"
25 | CHIP TRANSISTOR | 4 | Description | F4 "CHIP TRANSISTOR" 0 0 50 H I C CNN "Description"
25 | 2N5551S | 5 | Comment | F5 "2N5551S" 0 0 50 H I C CNN "Comment"
25 | SOT-23 | 6 | TYPE | F6 "SOT-23" 0 0 50 H I C CNN "TYPE"
25 | FIRST SILICON | 7 | MAKER | F7 "FIRST SILICON" 0 0 50 H I C CNN "MAKER"
26 | CHIP TRANSISTOR | 4 | Description | F4 "CHIP TRANSISTOR" 0 0 50 H I C CNN "Description"
26 | 2SA1981SY | 5 | Comment | F5 "2SA1981SY" 0 0 50 H I C CNN "Comment"
26 | SOT-23 | 6 | TYPE | F6 "SOT-23" 0 0 50 H I C CNN "TYPE"
26 | AUK | 7 | MAKER | F7 "AUK" 0 0 50 H I C CNN "MAKER"
27 | PIN HEADER | 4 | Description | F4 "PIN HEADER" 0 0 50 H I C CNN "Description"
27 | SMW2.5MM-7P | 5 | Comment | F5 "SMW2.5MM-7P" 0 0 50 H I C CNN "Comment"
27 | DIP-8 | 6 | TYPE | F6 "DIP-8" 0 0 50 H I C CNN "TYPE"
27 | YEONHO ELECTRONICS | 7 | MAKER | F7 "YEONHO ELECTRONICS" 0 0 50 H I C CNN "MAKER"
28 | SMD AMPLIFIER 1W | 4 | Description | F4 "SMD AMPLIFIER 1W" 0 0 50 H I C CNN "Description"
28 | AP4890 | 5 | Comment | F5 "AP4890" 0 0 50 H I C CNN "Comment"
28 | SOP8 | 6 | TYPE | F6 "SOP8" 0 0 50 H I C CNN "TYPE"
28 | APLUS | 7 | MAKER | F7 "APLUS" 0 0 50 H I C CNN "MAKER"
29 | SMD BUFFER | 4 | Description | F4 "SMD BUFFER" 0 0 50 H I C CNN "Description"
29 | ULN2003D1013TR | 5 | Comment | F5 "ULN2003D1013TR" 0 0 50 H I C CNN "Comment"
29 | SOP-16 | 6 | TYPE | F6 "SOP-16" 0 0 50 H I C CNN "TYPE"
29 | STMicroelectronics | 7 | MAKER | F7 "STMicroelectronics" 0 0 50 H I C CNN "MAKER"
30 | SMD DIODE SCHOTTKY | 4 | Description | F4 "SMD DIODE SCHOTTKY" 0 0 50 H I C CNN "Description"
30 | MBRAF3200T3G | 5 | Comment | F5 "MBRAF3200T3G" 0 0 50 H I C CNN "Comment"
30 | SMA | 6 | TYPE | F6 "SMA" 0 0 50 H I C CNN "TYPE"
30 | MDD, ON SEMICONDUCTOR | 7 | MAKER | F7 "MDD, ON SEMICONDUCTOR" 0 0 50 H I C CNN "MAKER"
31 | SMD DIODE TVS | 4 | Description | F4 "SMD DIODE TVS" 0 0 50 H I C CNN "Description"
31 | SMBJ15A | 5 | Comment | F5 "SMBJ15A" 0 0 50 H I C CNN "Comment"
31 | SMB | 6 | TYPE | F6 "SMB" 0 0 50 H I C CNN "TYPE"
31 | SAMYANG ELECTRONICS | 7 | MAKER | F7 "SAMYANG ELECTRONICS" 0 0 50 H I C CNN "MAKER"
32 | SMD ELECT CAPACITOR | 4 | Description | F4 "SMD ELECT CAPACITOR" 0 0 50 H I C CNN "Description"
32 | 220uF/6.3V | 5 | Comment | F5 "220uF/6.3V" 0 0 50 H I C CNN "Comment"
32 | SC 6.3X5.8 | 6 | TYPE | F6 "SC 6.3X5.8" 0 0 50 H I C CNN "TYPE"
32 | SAMYOUNG | 7 | MAKER | F7 "SAMYOUNG" 0 0 50 H I C CNN "MAKER"
33 | SMD INDUCTOR | 4 | Description | F4 "SMD INDUCTOR" 0 0 50 H I C CNN "Description"
33 | SC7850D-221K | 5 | Comment | F5 "SC7850D-221K" 0 0 50 H I C CNN "Comment"
33 | 7850 | 6 | TYPE | F6 "7850" 0 0 50 H I C CNN "TYPE"
33 | SUHKWANG | 7 | MAKER | F7 "SUHKWANG" 0 0 50 H I C CNN "MAKER"
34 | SMD JACK USB C TYPE | 4 | Description | F4 "SMD JACK USB C TYPE" 0 0 50 H I C CNN "Description"
34 | USB-TYPE-C-31-M-17 | 5 | Comment | F5 "USB-TYPE-C-31-M-17" 0 0 50 H I C CNN "Comment"
34 | SMD-6 | 6 | TYPE | F6 "SMD-6" 0 0 50 H I C CNN "TYPE"
34 | Korean-Hroparts-Elec | 7 | MAKER | F7 "Korean-Hroparts-Elec" 0 0 50 H I C CNN "MAKER"
35 | SMD MCU | 4 | Description | F4 "SMD MCU" 0 0 50 H I C CNN "Description"
35 | STM32G070RBT6 | 5 | Comment | F5 "STM32G070RBT6" 0 0 50 H I C CNN "Comment"
35 | LQFP64 | 6 | TYPE | F6 "LQFP64" 0 0 50 H I C CNN "TYPE"
35 | STMicroelectronics | 7 | MAKER | F7 "STMicroelectronics" 0 0 50 H I C CNN "MAKER"
36 | SMD MOSFET N-CHANNEL | 4 | Description | F4 "SMD MOSFET N-CHANNEL" 0 0 50 H I C CNN "Description"
36 | FDT86246L | 5 | Comment | F5 "FDT86246L" 0 0 50 H I C CNN "Comment"
36 | SOT-223 | 6 | TYPE | F6 "SOT-223" 0 0 50 H I C CNN "TYPE"
36 | FAIRCHILD | 7 | MAKER | F7 "FAIRCHILD" 0 0 50 H I C CNN "MAKER"
37 | SMD REGULATOR | 4 | Description | F4 "SMD REGULATOR" 0 0 50 H I C CNN "Description"
37 | LMT117-ADJ | 5 | Comment | F5 "LMT117-ADJ" 0 0 50 H I C CNN "Comment"
37 | SOT-223 | 6 | TYPE | F6 "SOT-223" 0 0 50 H I C CNN "TYPE"
37 | TGS | 7 | MAKER | F7 "TGS" 0 0 50 H I C CNN "MAKER"
38 | SMD SERIAL FLASH | 4 | Description | F4 "SMD SERIAL FLASH" 0 0 50 H I C CNN "Description"
38 | W25Q32JVSSIQ | 5 | Comment | F5 "W25Q32JVSSIQ" 0 0 50 H I C CNN "Comment"
38 | SOIC-8(208mil) | 6 | TYPE | F6 "SOIC-8(208mil)" 0 0 50 H I C CNN "TYPE"
38 | WINBOND | 7 | MAKER | F7 "WINBOND" 0 0 50 H I C CNN "MAKER"
39 | SMD VOICE | 4 | Description | F4 "SMD VOICE" 0 0 50 H I C CNN "Description"
39 | VLN1MM04S8X | 5 | Comment | F5 "VLN1MM04S8X" 0 0 50 H I C CNN "Comment"
39 | SOP-8 | 6 | TYPE | F6 "SOP-8" 0 0 50 H I C CNN "TYPE"
39 | SYNOOS | 7 | MAKER | F7 "SYNOOS" 0 0 50 H I C CNN "MAKER"
40 | SMD WAFER | 4 | Description | F4 "SMD WAFER" 0 0 50 H I C CNN "Description"
40 | 12505WR-02 | 5 | Comment | F5 "12505WR-02" 0 0 50 H I C CNN "Comment"
40 | SMD-2 | 6 | TYPE | F6 "SMD-2" 0 0 50 H I C CNN "TYPE"
40 | YEONHO ELECTRONICS | 7 | MAKER | F7 "YEONHO ELECTRONICS" 0 0 50 H I C CNN "MAKER"
41 | SMD WAFER | 4 | Description | F4 "SMD WAFER" 0 0 50 H I C CNN "Description"
41 | 12505WS-08 | 5 | Comment | F5 "12505WS-08" 0 0 50 H I C CNN "Comment"
41 | SMD-8 | 6 | TYPE | F6 "SMD-8" 0 0 50 H I C CNN "TYPE"
41 | YEONHO ELECTRONICS | 7 | MAKER | F7 "YEONHO ELECTRONICS" 0 0 50 H I C CNN "MAKER"
42 | SMD WAFER | 4 | Description | F4 "SMD WAFER" 0 0 50 H I C CNN "Description"
42 | 12505WS-09 | 5 | Comment | F5 "12505WS-09" 0 0 50 H I C CNN "Comment"
42 | SMD-9 | 6 | TYPE | F6 "SMD-9" 0 0 50 H I C CNN "TYPE"
42 | YEONHO ELECTRONICS | 7 | MAKER | F7 "YEONHO ELECTRONICS" 0 0 50 H I C CNN "MAKER"
43 | SPEAKER | 4 | Description | F4 "SPEAKER" 0 0 50 H I C CNN "Description"
43 | TDM15A-8-L055C0.5S-0.3D | 5 | Comment | F5 "TDM15A-8-L055C0.5S-0.3D" 0 0 50 H I C CNN "Comment"
43 | ASS'Y | 6 | TYPE | F6 "ASS'Y" 0 0 50 H I C CNN "TYPE"
43 | NCEI | 7 | MAKER | F7 "NCEI" 0 0 50 H I C CNN "MAKER"
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

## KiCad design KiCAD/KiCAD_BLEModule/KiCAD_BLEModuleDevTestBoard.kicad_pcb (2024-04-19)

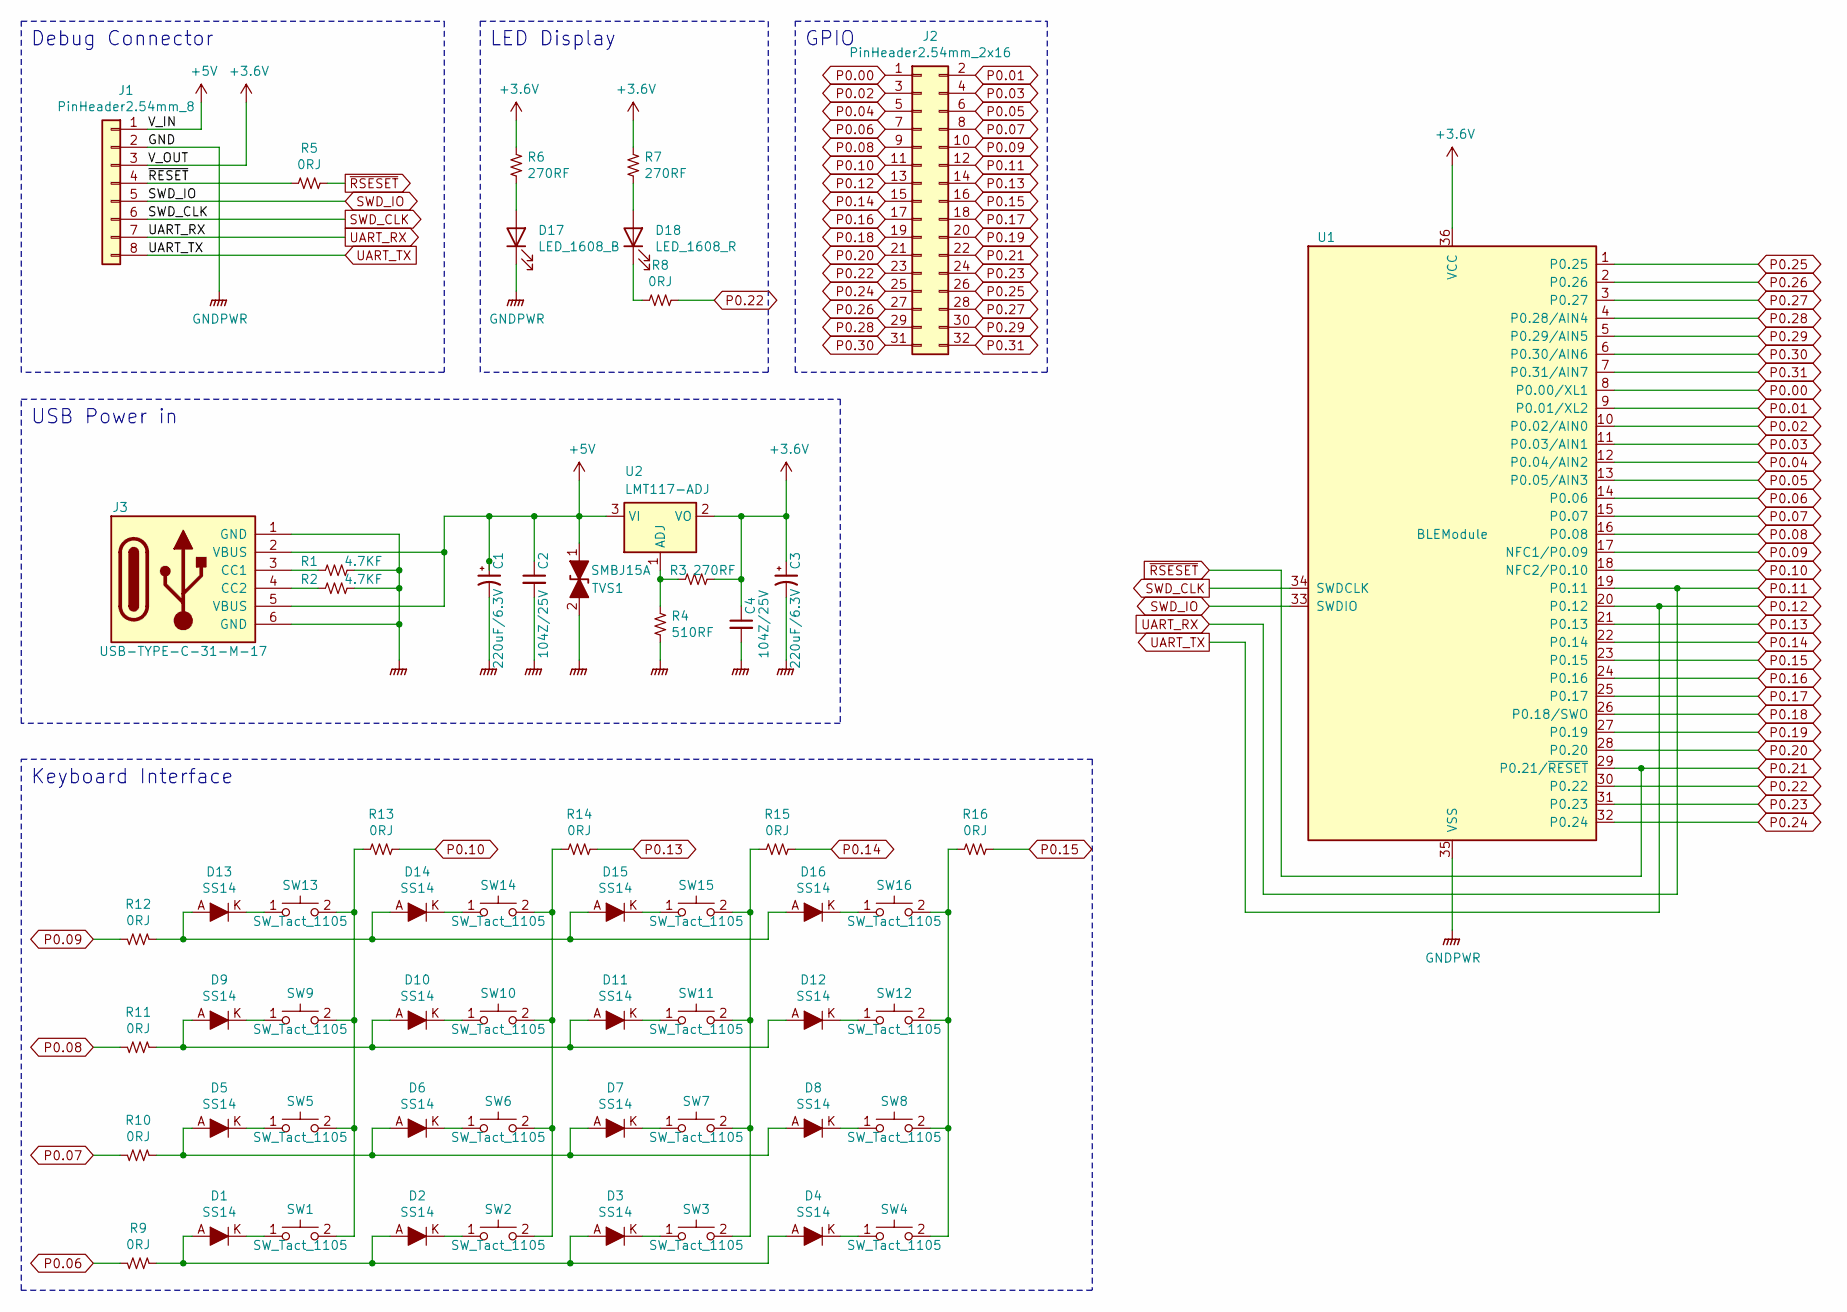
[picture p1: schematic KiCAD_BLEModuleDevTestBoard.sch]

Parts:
C1, C3: CAP_220uF_6.3V_SC6.3X5.8; C_Elec_6.3x5.8; PartName 220uF/6.3V
C2, C4: CAP_104Z_25V_1608; C_0603_1608Metric; PartName 104Z/25V
D1, D2, D3, D4, D5, D6, D7, D8, D9, D10, D11, D12, D13, D14, D15, D16: SS14; DO-214AC
D17: LED_1608_B; LED_0603_1608Metric
D18: LED_1608_R; LED_0603_1608Metric
J1: PinHeader2.54mm_8; PinHeader_1x08_P2.54mm_Vertical; PartName PinHeader2.54mm-8P
J2: PinHeader2.54mm_2x16; PinSocket_2x16_P2.54mm_Vertical
J3: USB-TYPE-C-31-M-17; TYPE-C-31-M-17-1; PartName USB-TYPE-C-31-M-17
R1, R2: R_4.7KF; R_0603_1608Metric; PartName 4.7KF
R3, R6, R7: R_270RF; R_0603_1608Metric; PartName 270RF
R4: R_510RF; R_0603_1608Metric; PartName 510RF
R5, R8, R9, R10, R11, R12, R13, R14, R15, R16: R_0RJ; R_0603_1608Metric; PartName 0RJ
SW1, SW2, SW3, SW4, SW5, SW6, SW7, SW8, SW9, SW10, SW11, SW12, SW13, SW14, SW15, SW16: SW_Tact_1105; SW_PUSH_6mm_H5mm; PartName ITS-1105-5mm
TVS1: SMBJ15A; D_SMB; PartName SMBJ15A
U1: BLEModule
U2: LMT117-ADJ; SOT-223-3_TabPin2; PartName LMT117-ADJ

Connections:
+3.6V: C3.1, C4.1, J1.3, R3.1, R6.1, R7.1, U1.36 (VCC), U2.2 (VO)
+5V: C1.1, C2.1, J1.1, J3.2 (VBUS), J3.5 (VBUS), TVS1.1 (A1), U2.3 (VI)
/~RESET: J1.4, R5.2
GNDPWR: C1.2, C2.2, C3.2, C4.2, D17.1 (K), J1.2, J3.1 (GND), J3.6 (GND), R1.1, R2.1, R4.2, TVS1.2 (A2), U1.35 (VSS)
unnamed: D1.A, D2.A, D3.A, D4.A, R9.2
unnamed: D1.K, SW1.1
unnamed: D2.K, SW2.1
unnamed: D3.K, SW3.1
unnamed: D4.K, SW4.1
unnamed: D5.A, D6.A, D7.A, D8.A, R10.2
unnamed: D5.K, SW5.1
unnamed: D6.K, SW6.1
unnamed: D7.K, SW7.1
unnamed: D8.K, SW8.1
unnamed: D9.K, SW9.1
unnamed: D9.A, D10.A, D11.A, D12.A, R11.2
unnamed: D10.K, SW10.1
unnamed: D11.K, SW11.1
unnamed: D12.K, SW12.1
unnamed: D13.A, D14.A, D15.A, D16.A, R12.2
unnamed: D13.K, SW13.1
unnamed: D14.K, SW14.1
unnamed: D15.K, SW15.1
unnamed: D16.K, SW16.1
unnamed: D17.2 (A), R6.2
unnamed: D18.1 (K), R8.2
unnamed: D18.2 (A), R7.2
unnamed: J3.3 (CC1), R1.2
unnamed: J3.4 (CC2), R2.2
unnamed: R3.2, R4.1, U2.1 (ADJ)
unnamed: R13.2, SW1.2, SW5.2, SW9.2, SW13.2
unnamed: R14.2, SW2.2, SW6.2, SW10.2, SW14.2
unnamed: R15.2, SW3.2, SW7.2, SW11.2, SW15.2
unnamed: R16.2, SW4.2, SW8.2, SW12.2, SW16.2
P0.00: J2.1, U1.8 (P0.00/XL1)
P0.01: J2.2, U1.9 (P0.01/XL2)
P0.02: J2.3, U1.10 (P0.02/AIN0)
P0.03: J2.4, U1.11 (P0.03/AIN1)
P0.04: J2.5, U1.12 (P0.04/AIN2)
P0.05: J2.6, U1.13 (P0.05/AIN3)
P0.06: J2.7, R9.1, U1.14 (P0.06)
P0.07: J2.8, R10.1, U1.15 (P0.07)
P0.08: J2.9, R11.1, U1.16 (P0.08)
P0.09: J2.10, R12.1, U1.17 (NFC1/P0.09)
P0.10: J2.11, R13.1, U1.18 (NFC2/P0.10)
P0.11: J1.7, J2.12, U1.19 (P0.11)
P0.12: J1.8, J2.13, U1.20 (P0.12)
P0.13: J2.14, R14.1, U1.21 (P0.13)
P0.14: J2.15, R15.1, U1.22 (P0.14)
P0.15: J2.16, R16.1, U1.23 (P0.15)
P0.16: J2.17, U1.24 (P0.16)
P0.17: J2.18, U1.25 (P0.17)
P0.18: J2.19, U1.26 (P0.18/SWO)
P0.19: J2.20, U1.27 (P0.19)
P0.20: J2.21, U1.28 (P0.20)
P0.21: J2.22, R5.1, U1.29 (P0.21/~RESET)
P0.22: J2.23, R8.1, U1.30 (P0.22)
P0.23: J2.24, U1.31 (P0.23)
P0.24: J2.25, U1.32 (P0.24)
P0.25: J2.26, U1.1 (P0.25)
P0.26: J2.27, U1.2 (P0.26)
P0.27: J2.28, U1.3 (P0.27)
P0.28: J2.29, U1.4 (P0.28/AIN4)
P0.29: J2.30, U1.5 (P0.29/AIN5)
P0.30: J2.31, U1.6 (P0.30/AIN6)
P0.31: J2.32, U1.7 (P0.31/AIN7)
SWD_CLK: J1.6, U1.34 (SWDCLK)
SWD_IO: J1.5, U1.33 (SWDIO)

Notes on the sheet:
Debug Connector
GPIO
LED Display
USB Power in
Keyboard Interface

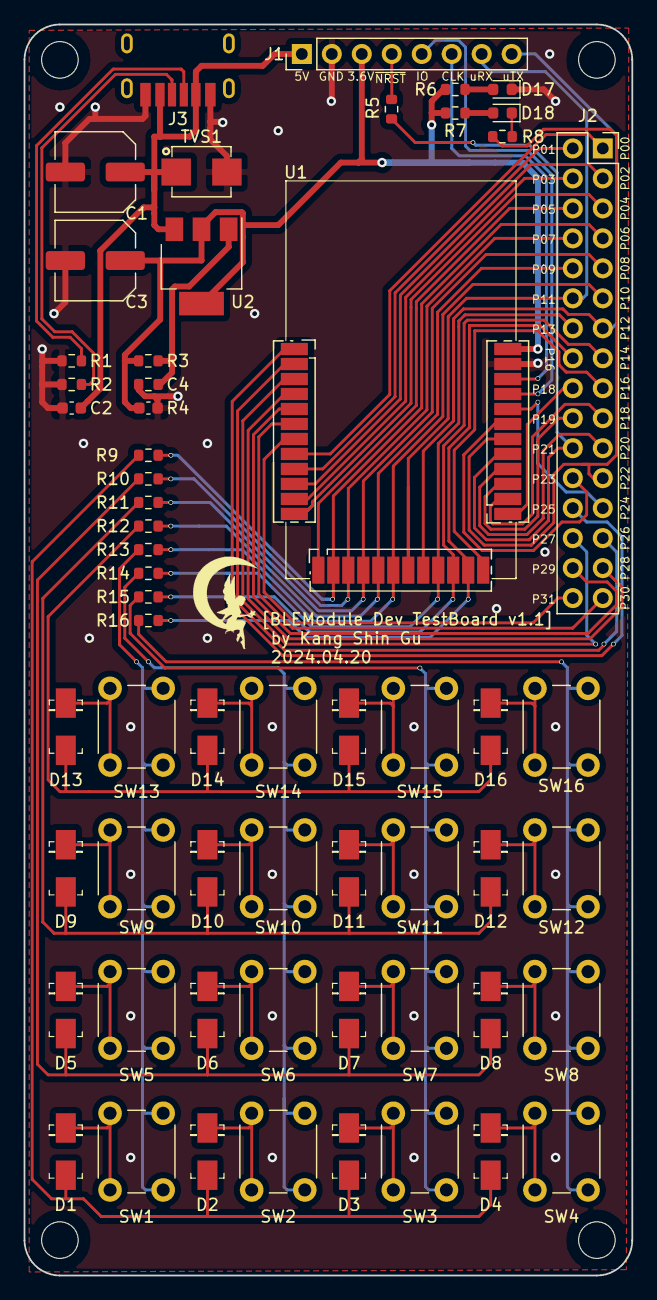
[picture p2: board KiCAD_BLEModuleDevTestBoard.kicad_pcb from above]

Board: 2 copper layers, 51.5 x 106.0 mm, 60 parts (0 on the bottom side), 68 nets.

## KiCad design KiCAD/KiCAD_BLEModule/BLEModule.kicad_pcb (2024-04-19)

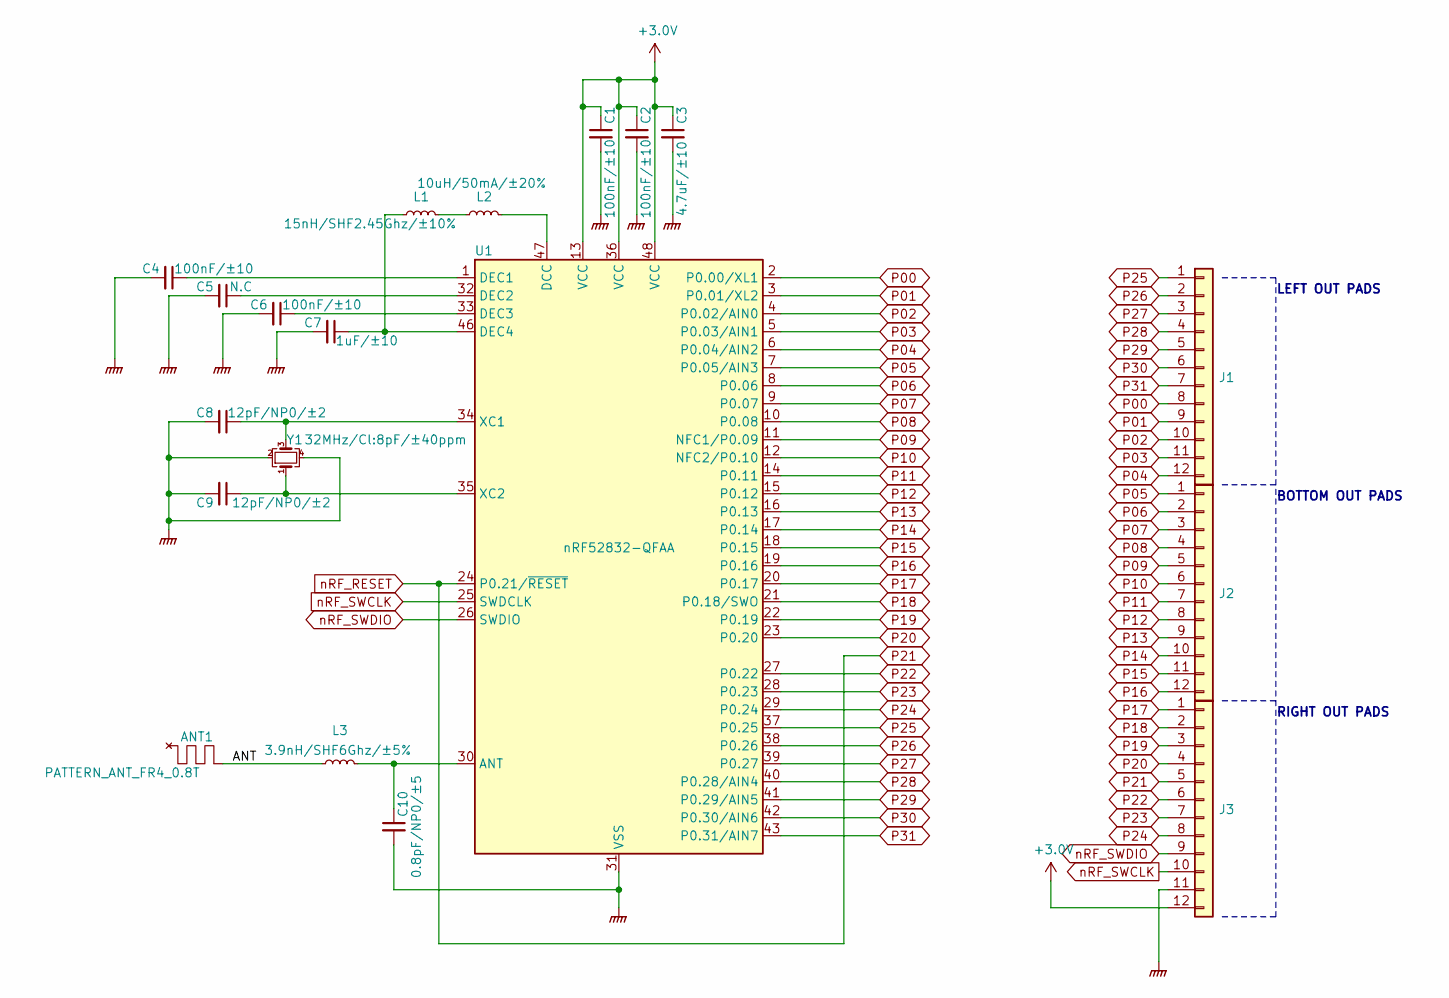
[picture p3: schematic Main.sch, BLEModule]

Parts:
ANT1: PATTERN_ANT_FR4_0.8T; ANT_PATTERN_FR4_0.8T
C1, C2, C4, C6: CAP_100nF_1005; C_0402_1005Metric; PartName 100nF/±10
C3: CAP_4.7uF_1005; C_0402_1005Metric; PartName 4.7uF/±10
C5: CAP_N.C_1005; C_0402_1005Metric; PartName N.C
C7: CAP_1uF_1005; C_0402_1005Metric; PartName 1uF/±10
C8, C9: CAP_12pF_1005; C_0402_1005Metric; PartName 12pF/NP0/±2
C10: CAP_0.8pF_1005; C_0402_1005Metric; PartName 0.8pF/NP0/±5
J1, J2, J3: CastellatedPinHeader1.27mm_12; CastellatedPinHeader_1x12_P1.27mm_VerticalR
L1: L_15nH; L_0402_1005Metric; PartName 15nH/SHF2.45Ghz/±10%
L2: L_10uH; L_0603_1608Metric; PartName 10uH/50mA/±20%
L3: L_3.9nH; L_0402_1005Metric; PartName 3.9nH/SHF6Ghz/±5%
U1: nRF52832-QFAA; QFN-48-1EP_6x6mm_P0.4mm_EP4.3x4.3mm; PartName nRF52832-QFAA
Y1: Y_32MHz; Crystal_SMD_2016-4Pin_2.0x1.6mm; PartName 32MHz/Cl:8pF/±40ppm

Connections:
+30V: C1.1, C2.1, C3.1, J3.12, U1.13 (VCC), U1.36 (VCC), U1.48 (VCC)
/Main/ANT: ANT1.1, L3.1
GNDPWR: C1.2, C2.2, C3.2, C4.2, C5.2, C6.2, C7.2, C8.2, C9.2, C10.2, J3.11, U1.31 (VSS), U1.45 (VSS), U1.49 (VSS), Y1.2, Y1.4
unnamed: C4.1, U1.1 (DEC1)
unnamed: C5.1, U1.32 (DEC2)
unnamed: C6.1, U1.33 (DEC3)
unnamed: C7.1, L1.1, U1.46 (DEC4)
unnamed: C8.1, U1.34 (XC1), Y1.3
unnamed: C9.1, U1.35 (XC2), Y1.1
unnamed: C10.1, L3.2, U1.30 (ANT)
unnamed: L1.2, L2.1
unnamed: L2.2, U1.47 (DCC)
P00: J1.8, U1.2 (P0.00/XL1)
P01: J1.9, U1.3 (P0.01/XL2)
P02: J1.10, U1.4 (P0.02/AIN0)
P03: J1.11, U1.5 (P0.03/AIN1)
P04: J1.12, U1.6 (P0.04/AIN2)
P05: J2.1, U1.7 (P0.05/AIN3)
P06: J2.2, U1.8 (P0.06)
P07: J2.3, U1.9 (P0.07)
P08: J2.4, U1.10 (P0.08)
P09: J2.5, U1.11 (NFC1/P0.09)
P10: J2.6, U1.12 (NFC2/P0.10)
P11: J2.7, U1.14 (P0.11)
P12: J2.8, U1.15 (P0.12)
P13: J2.9, U1.16 (P0.13)
P14: J2.10, U1.17 (P0.14)
P15: J2.11, U1.18 (P0.15)
P16: J2.12, U1.19 (P0.16)
P17: J3.1, U1.20 (P0.17)
P18: J3.2, U1.21 (P0.18/SWO)
P19: J3.3, U1.22 (P0.19)
P20: J3.4, U1.23 (P0.20)
P21: J3.5, U1.24 (P0.21/~RESET)
P22: J3.6, U1.27 (P0.22)
P23: J3.7, U1.28 (P0.23)
P24: J3.8, U1.29 (P0.24)
P25: J1.1, U1.37 (P0.25)
P26: J1.2, U1.38 (P0.26)
P27: J1.3, U1.39 (P0.27)
P28: J1.4, U1.40 (P0.28/AIN4)
P29: J1.5, U1.41 (P0.29/AIN5)
P30: J1.6, U1.42 (P0.30/AIN6)
P31: J1.7, U1.43 (P0.31/AIN7)
nRF_SWCLK: J3.10, U1.25 (SWDCLK)
nRF_SWDIO: J3.9, U1.26 (SWDIO)

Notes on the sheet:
LEFT OUT PADS
BOTTOM OUT PADS
RIGHT OUT PADS

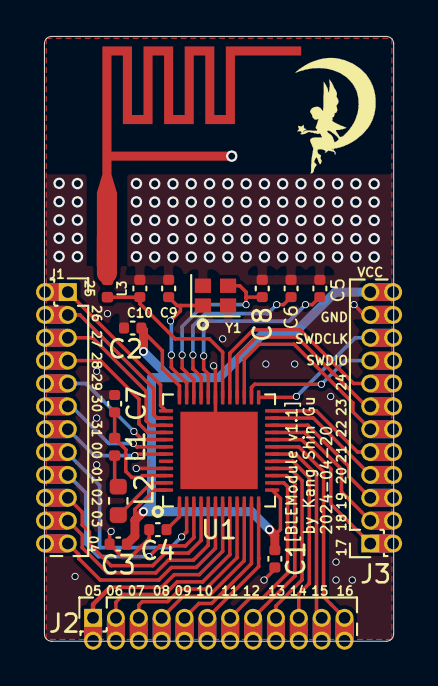
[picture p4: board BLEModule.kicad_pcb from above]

Board: 2 copper layers, 19.4 x 33.6 mm, 19 parts (0 on the bottom side), 46 nets.

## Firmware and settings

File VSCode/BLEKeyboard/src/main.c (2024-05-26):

// APIs Search Site
// https://docs.zephyrproject.org/apidoc/latest/index.html

#include "include.h"
#include <zephyr/drivers/gpio.h>

#include "BleHidKeyboard.h"
#include "gpio.h"

LOG_MODULE_REGISTER(my_module, LOG_LEVEL_INF);

int main(void)
{
	int ret;
	printk("[main] Start\n");

	ret = gpio_init();
	if (ret < 0)
	{
		printk("[gpio_init] failed\n");
		return -1;
	}
	
	ret = gpio_thread_start();
	if (ret < 0)
	{
		printk("[gpio_thread_start] failed\n");
		return -1;
	}

	ret = bleHid_init();
	if (ret < 0)
	{
		printk("[bleHid_init] failed\n");
		return -1;
	}
	
	ret = bleHid_thread_start();
	if (ret < 0)
	{
		printk("[bleHid_thread_start] failed\n");
		return -1;
	}

	printk("[main] Loop STD\n");
	
	while (1)
	{
		k_msleep(1000);
	}
	return 0;
}

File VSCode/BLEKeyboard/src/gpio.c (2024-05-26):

/**
 * @file gpio.c
 * @author Kang Shin Gu (indra1469@naver.com)
 * @brief GPIO 초기화 와 업데이트 관련
 * @version 1.0
 * @date 2024-05-25
 * 
 * @copyright Copyright (c) 2024
 */
#include "gpio.h"

#include <zephyr/shell/shell.h>

// for gpio control func rename
#define gpio_set gpio_pin_set_dt
#define gpio_get gpio_pin_get_dt
#define gpio_tgl gpio_pin_toggle_dt

// for logging
LOG_MODULE_DECLARE(my_module);

// for thread
K_THREAD_STACK_DEFINE(thread_stack_area_gpio_0, 256);
K_THREAD_STACK_DEFINE(thread_stack_area_gpio_1, 512);
static struct k_thread thread_data_gpio_0;
static struct k_thread thread_data_gpio_1;

// for Status Led
static LEDstatus isSetting = LEDstatus_isBlink;

// for keyStatus

#define KEY_STATUS_MSG_QUEUE_MAX_CNT 4

K_MSGQ_DEFINE(key_status_msg_queue,
			  sizeof(key_status_msg_data),
			  KEY_STATUS_MSG_QUEUE_MAX_CNT,
			  4);

/**
 * ------------ define gpioID -----------------
*/
#define GPIO_SPEC_AND_COMMA(node_id) GPIO_DT_SPEC_GET(node_id, gpios),

#define LED0_NODE DT_ALIAS(led0)
static const struct gpio_dt_spec led0 = GPIO_DT_SPEC_GET(LED0_NODE, gpios);

static const struct gpio_dt_spec btnpwr[] = {
    GPIO_DT_SPEC_GET(DT_NODELABEL(pins), btnpwr_0_gpios),
    GPIO_DT_SPEC_GET(DT_NODELABEL(pins), btnpwr_1_gpios),
    GPIO_DT_SPEC_GET(DT_NODELABEL(pins), btnpwr_2_gpios),
    GPIO_DT_SPEC_GET(DT_NODELABEL(pins), btnpwr_3_gpios),
};

static const struct gpio_dt_spec btnsens[] = {
    GPIO_DT_SPEC_GET(DT_NODELABEL(btn_0), gpios),
    GPIO_DT_SPEC_GET(DT_NODELABEL(btn_1), gpios),
    GPIO_DT_SPEC_GET(DT_NODELABEL(btn_2), gpios),
    GPIO_DT_SPEC_GET(DT_NODELABEL(btn_3), gpios),
};

/**
 * ------------ define gpioID end -----------------
*/

/**
 * @brief 준비 + 초기화
 * 
 * @param spec gpioID (GPIO_DT_SPEC_GET을 통해 얻은 ID)
 * @param extra_flags 추가할 GPIO속성 (aleady setted ACTIVE)
 * @return int 
 */
static int pin_init(const struct gpio_dt_spec *spec, gpio_flags_t extra_flags)
{
	if (!gpio_is_ready_dt(spec))
	{
		return -1;
	}

	return gpio_pin_configure_dt(spec, extra_flags);
}
int gpio_init(void)
{
	int ret = 0;
	ret = pin_init(&led0, GPIO_OUTPUT_INACTIVE);
	if (ret < 0)
	{
		return -1;
	}

	for (int i = 0; i < ARRAY_SIZE(btnpwr); i++)
	{
		// ret = pin_init(&btnpwr[i], GPIO_OUTPUT_ACTIVE);
		ret = pin_init(&btnpwr[i], GPIO_OUTPUT_INACTIVE);
		if (ret < 0)
		{
			return -1;
		}
	}

	for (int i = 0; i < ARRAY_SIZE(btnsens); i++)
	{
		ret = pin_init(&btnsens[i], GPIO_INPUT);
		if (ret < 0)
		{
			return -1;
		}
	}

	return 0;
}

static void thread_LedUpdate(void *arg1, void *arg2, void *arg3)
{
    // arg1, arg2, arg3 사용하지 않음을 명시
    (void)arg1;
    (void)arg2;
    (void)arg3;

	int ret = 0;
	while (true)
	{
		if (isSetting == LEDstatus_isBlink)
		{
			ret = gpio_tgl(&led0);
			if (ret < 0)
				return;
			k_msleep(250);
		}
		else
		{
			k_msleep(10);
		}
	}
}

/**
 * @brief 키보드 입력 체크(쓰레드)
 * 
 * @param arg1 no use
 * @param arg2 no use
 * @param arg3 no use
 */
static void thread_KeyInputUpdate(void *arg1, void *arg2, void *arg3)
{
	// arg1, arg2, arg3 사용하지 않음을 명시
	(void)arg1;
	(void)arg2;
	(void)arg3;

	uint16_t callcnt = 0;
	uint8_t rowIdx = 0;
	int ret = 0;

	while (true)
	{
		// 메시지 큐 확인
		if (k_msgq_num_free_get(&key_status_msg_queue) == 0)
		{
			// 메시지 큐가 가득 찼을 경우

			// option1. 모든 메시지를 비우기
			k_msgq_purge(&key_status_msg_queue);

			// option2. 메시지 1개 버리기
			// key_status_msg_data msg_data_discard;
			// k_msgq_get(&key_status_msg_queue, &msg_data_discard, K_NO_WAIT);
		}

		for (rowIdx = 0; rowIdx < 4; rowIdx++)
		{

			// 체크할 행 지정
			{
				ret = gpio_set(&btnpwr[rowIdx], 1);
				if (ret != RESERT_OK)
				{
					printk("Err. [thread_KeyInputUpdate] gpio_set\n");
					return;
				}
			}
			k_msleep(2);

			// GPIO Input(키입력) 체크
			{
				// printk("btnsens [%d] %d %d %d %d\n", rowIdx, gpio_get(&btnsens[0]), gpio_get(&btnsens[1]), gpio_get(&btnsens[2]), gpio_get(&btnsens[3]));
				key_status_msg_data msg_data;
				msg_data.rowIdx = rowIdx;
				for (size_t i = 0; i < 4; i++)
				{
					msg_data.colKeyInput[i] = gpio_get(&btnsens[i]);
				}

				// 메시지 발송
				ret = k_msgq_put(&key_status_msg_queue, &msg_data, K_NO_WAIT);
				if (ret != RESERT_OK)
				{
					printk("Err. [thread_KeyInputUpdate] k_msgq_put\n");
					return;
				}
			}
			k_msleep(2);

			// GPIO 초기화
			{
				ret = gpio_set(&btnpwr[rowIdx], 0);
				if (ret != RESERT_OK)
				{
					printk("Err. [thread_KeyInputUpdate] gpio_set\n");
					return;
				}
			}

			++callcnt;
			k_msleep(6);
		}
	}
}

int gpio_thread_start(void)
{
	k_thread_create(&thread_data_gpio_0, thread_stack_area_gpio_0,
					K_THREAD_STACK_SIZEOF(thread_stack_area_gpio_0),
					thread_LedUpdate,
					NULL, NULL, NULL,
					7, 0, K_NO_WAIT);
					
	k_thread_create(&thread_data_gpio_1, thread_stack_area_gpio_1,
					K_THREAD_STACK_SIZEOF(thread_stack_area_gpio_1),
					thread_KeyInputUpdate,
					NULL, NULL, NULL,
					3, 0, K_NO_WAIT);

    k_thread_start(&thread_data_gpio_0);
    k_thread_start(&thread_data_gpio_1);

	return 0;
}
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

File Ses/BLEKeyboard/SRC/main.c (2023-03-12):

#include <stdint.h>
#include <stdio.h>

#include "module_nrf_log.h"
#include "module_app_timer.h"
#include "module_pwr_mgmt.h"
#include "module_app_scheduler.h"
#include "module_ble.h"

int main()
{
	// nrf기본 로그 시스템을 초기화 한다.
	log_init();
	
	// 타이머 시스템을 초기화 한다. 배터리 확인용 타이머를 생성한다.
	timers_init();
	
	// 보드설정의 초기화
	// 주로 led와 Key이지만 그외의 것들도 있다.
	// Key의 경우 인터럽트를 이용하고 있다.
	//buttons_leds_init(&erase_bonds);
	
	// 전원부 설정을 초기화
	power_management_init();
	
	// BLE 소프트 디바이스 활성화
	ble_stack_init();
	
	// 스케쥴러 모듈을 초기화
	// 현재 프로젝트는 AppTimer와 소프트디바이스가 스케쥴러 기반으로 설정되어 있다.
	// NRF_SDH_DISPATCH_MODEL을 참고
	scheduler_init();
	
	// GAP (Generic Access Profile)의 정보를 입력하고 소프트디바이스에 보내준다.
	// 장치의 정보를 보내주는데 사용
	// 디바이스 이름, 종류 등
	gap_params_init();
	
	// GATT는 (Generic Attribute Profile)의  정보를 입력하고 소프트디바이스에 보내준다.
	// 두 BLE 장치가 데이터를 교환하는 방식을 정의하는 데 사용
	// MTU 및 GAP 크기
	gatt_init();
	
	// BLE 광고 초기화
	// LE장치 사용 등을 결정한다.
	advertising_init();
	
	// 서비스 초기화
	services_init();
	
	// 배터리용 삼각파형 생성기다. 의미 없다.
	// 추후 배터리값을 어떻게 BLE에 보내는지만 확인하자
	//sensor_simulator_init();
	
	// BLE 컨넥트시에 대한 설정
	// timeOut등의 설정을 한다.
	conn_params_init();
	
	// 전송되지 못한 데이터(키)를 저장할 공간 초기화
	// 아마 필요 없을 듯 하다.
	//buffer_init();
	
	// BLE 피어 메니져 초기화
	// 필수요소는 아니지만 피어 관리(재연결등) 및 보안 강화를 위해 사용된다.
	peer_manager_init();
	
	// 앱 타이머를 시작한다.
	// 배터리 체크용이다.
	//timers_start();
	
	// BLE 광고 시작
	//advertising_start(erase_bonds);
	advertising_start(false);

	// Enter main loop.
	for (;;)
	{
		//idle_state_handle();
	}
}

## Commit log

2023-02-26 KSG : 기본 파일 업로드 (ignore, 라이선스 등)
2023-02-26 KSG : 블루투스 레퍼런스 자료 및 Util 업로드
2023-02-26 KSG : nRF5 SDK 및 SES 설정값 업로드
2023-03-12 KSG : 신규 프로젝트 생성(nRF52832/s132형태) - 비어있는 깨끗한 빌드. 빌드 시 성공.
2023-03-12 KSG : 클린빌드 설정 중 미진한 부분 재조정(해당 버전이 진짜 클린 빌드)
2023-03-12 KSG : 기본 요소 구성중
2024-03-30 KSG : 졸업과제용 BLE 모듈 제작(주문 완료)
    [201228 CPP-093AB(demo2)_BOM.xlsx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]
2024-04-06 KSG : BLE 모듈 개발용 테스트 보드 (키보드레이아웃) 아트워크 완료
    [KiCAD_BLEModuleDevTestBoard.kicad_pcb, KiCAD_BLEModuleDevTestBoard.sch, OutPulsePart.sch]
2024-04-06 KSG : BLE모듈 레이아웃에 에 라운드 추가
    [BLEModule.kicad_pcb]
2024-04-06 KSG : 거버파일 생성 & 잘못된 다이오드 정보 수정
    [KiCAD_BLEModuleDevTestBoard-B_Cu.gbr, KiCAD_BLEModuleDevTestBoard-B_Mask.gbr, KiCAD_BLEModuleDevTestBoard-B_Paste.gbr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]
2024-04-19 KSG : 아트워크 프린트 오기 수정
    [BLEModule-B_Cu.gbr, BLEModule-B_Mask.gbr, BLEModule-B_Paste.gbr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]
2024-04-20 KSG : 불필요 파일 제거
    [Bluetooth.sch]
2024-04-20 KSG : 제퍼 빌드 환경 구성 완료 LED블링크 + RTT 터미널 테스트 빌드 제작
2024-04-20 KSG : 테스트 코드 수정
    [main.c]
2024-04-20 KSG : 키보드 입력 프로토타입 테스트 완료
2024-04-21 KSG : GPIO update를 Thread형태로 변경
2024-05-18 KSG : BLE HID GATT 브로드캐스팅 셋팅(검색 테스트 확인)
2024-05-19 KSG : 인증모드로 변경. 연결끊김 후 ReAdvertising 기능 활성화.
2024-05-25 KSG : GPIO에서 Ble로 Key값 상태 MSG 송/수신 로직 추가
2024-05-25 KSG : 키 입력시 BLE HID 키송출("123456") 테스트 예제 제작
2024-05-25 KSG : 프로필 2개 제작 시작 - 프로필 형태로 구조 변경
2024-05-25 KSG : 프로필 2개 제작 시작 - 프로필 2개 적용 완료. 키 발송 테스트 완료.
2024-05-26 KSG : 다중키 입력 기반 마련(다중키 검증로직 개선 필요->기존키 비교 삭제/추가)
2024-05-26 KSG : 다중키 입력 로직 개선(검증용 링큐버퍼 적용)
2024-05-26 KSG : 구조 개선 - 공통함수를 하나로 묶음
2024-05-26 KSG : Connect, NumLock 상태 LED 표출 적용
2024-05-26 KSG : 불필요 주석 코드 삭제
2024-05-26 KSG : 크래시 안정화 (GPIO 변경후 대기시간이 짧음으로 인해 발생으로 보임)
2024-06-06 KSG : 레포트 맵에서 키보드 입력 사이즈(최대 입력 키 개수) 수정 (6->8)
    [bleProfile_HidKeyboard_def.c]
